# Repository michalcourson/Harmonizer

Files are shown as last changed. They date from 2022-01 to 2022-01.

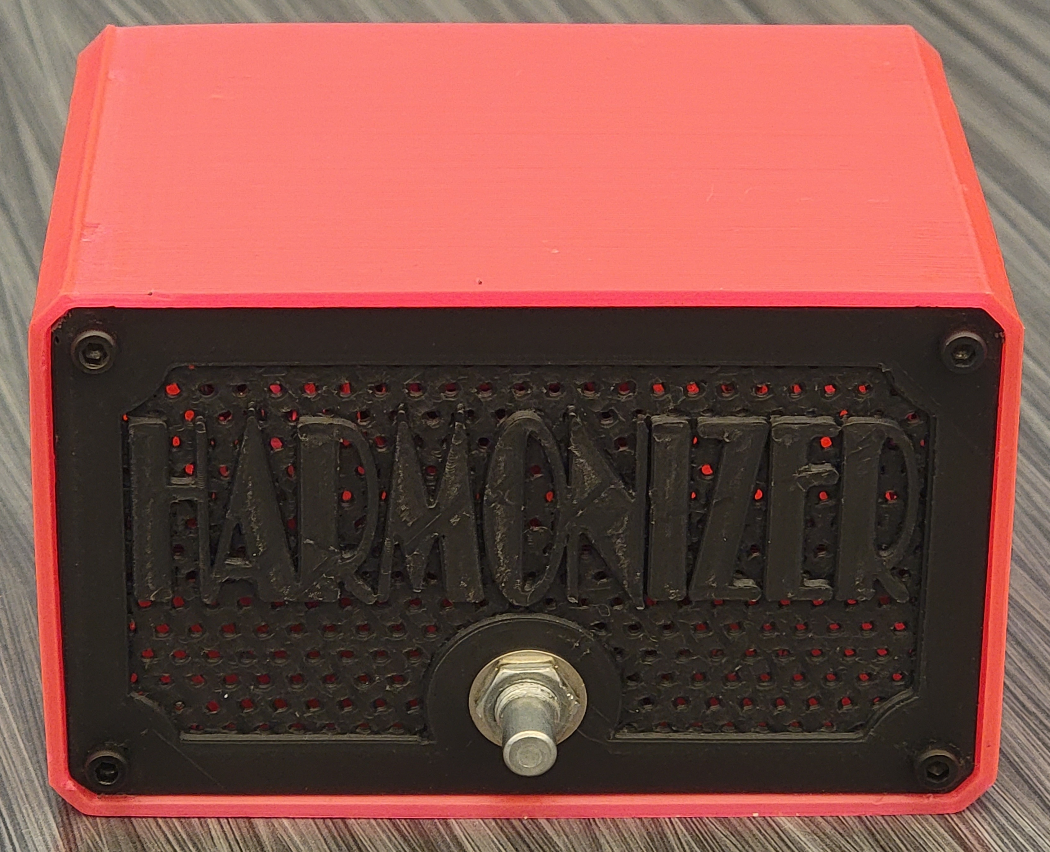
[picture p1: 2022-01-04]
design/assembly_images/Harmonizer_face.png

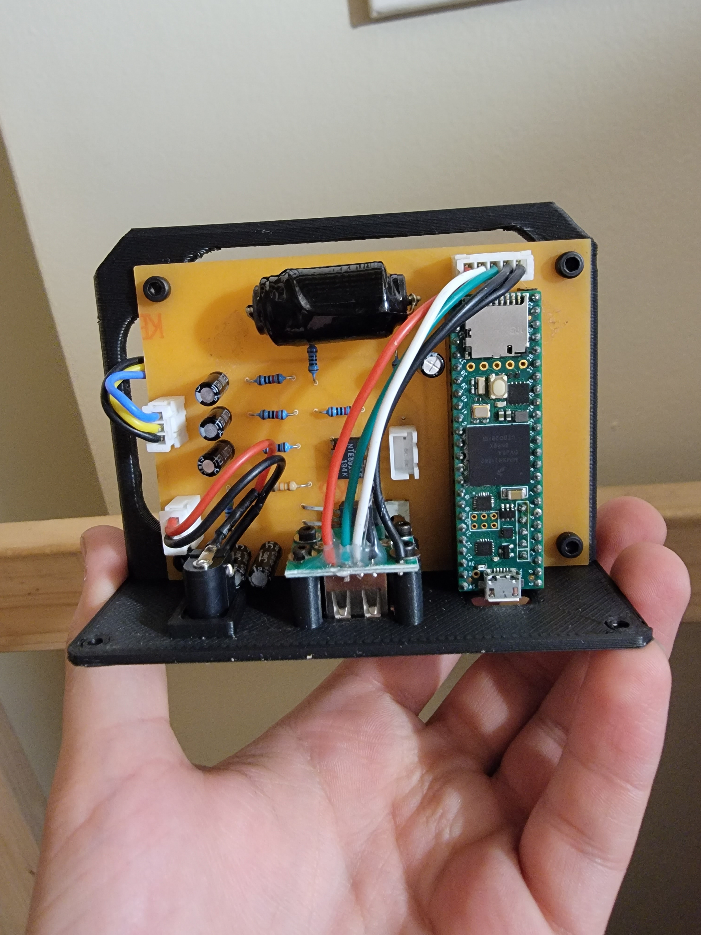
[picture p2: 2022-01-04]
design/assembly_images/Harmonizer_internal2.png

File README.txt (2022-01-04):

Team members:
	Audrey Cooke
	audeo@umich.edu
 
	Michal Courson 
	mcourson@umich.edu
 
	Daniel Kohler
	danikohl@umich.edu
 
	Allanah Matthews
	allanahm@umich.edu
 
Zipfile Contents:
COPYRIGHT.TXT
	--Document which highlights the necessary copyright provisions for the Harmonizer project

2021-Team-Harmonizer-final.pdf
	--Final report for the Harmonizer project.  

2021-Team-Harmonizer-slides.pdf
	--Final presentation slide-deck to be presented in class. 
 
2021-Team-Harmonizer-poster.pdf
	--Final project poster to be presented at the Fall 2021 CoE Design Expo

vidoes 
	--Folder which includes real time demonstration videos of the Harmonizer for our final presentation slides

src 
	--Folder which contains the source code for our project
		--Includes code written for the offline python and offline C++ prototypes of our algorithms.  
		Each offline folder includes its own USAGE.TXT to outline how to use the code.

		--The OVERVIEW.TXT file provides an overview of each embedded code file needed for the Teensy.
		It also gives a basic overview of the software operation of the system. 

		--The USAGE.TXT file contains user-interface information which details the designated inputs 
		and outputs for the Harmonizer on the Teensy itself. 

		--The INSTALL.TXT file contains instructions for software installation on the Teensy.  It also 
		details the designated folder locations for specific files in order for the Harmonizer to successfully run in real time. 

		--The to_audio_library_folder houses the files which need to be stored in the Audio folder for the Teensy.

		--The to_core_teensy4_folder houses the files which need to be stored in the CoreTeensy4 folder for the Teensy. 

		--The harmonizer folder includes the .ino file which needs to be compiled on the Teensy in order for the system to operate in real time. 
data 
	--The audio subfolder includes results of pitch shifting a tritonal signal (at a note frequency of C3) using the TD-PSOLA algorithm, 
	the Phase-Vocoding algorithm, and both of these algorithms together with crossfading implemented at the switching threshold.  
	The results from each of these tests can be compared to Target_Output.wav

	--The figures subfolder includes images and plots which are used in the final presentation and final report. 

design 
	--This folder houses subfolders which are designated for files associated with the PCB design, the package design and images of the assembly process.
  
	--The pdf for bill of materials is also included in this folder (not included in its own subfolder).

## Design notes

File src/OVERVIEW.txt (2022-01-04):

OVERVIEW
Files:
harmonizer/harmonizer.ino: driver sketch to be loaded onto a Teensy 4.1, 
instantiates Audio processing objects that pitch shift the input signal. Four concurrent shifts are mixed together and sent to the output.

to_audio_library_folder/analyze_notefreq.cpp/analyse_notefreq.h: modification of Audio Library pitch estimator to work with block size of 1024

to_audio_library_folder/Audio.h: modification of Audio Library file to include effect_pitch_shift.h

to_core_teensy4_folder/AudioStream.h: modification of Audio Library Stream objects to use block size of 1024 instead of 128

to_audio_library_folder/effect_pitch_shift.cpp/effect_pitch_shift.h: Definition and implementation of new processing object to perform pitch shifting

BASIC OPERATION
The Audio Library has an infrastructure that calls the virtualized update() function on any object
whenever a new input block is passed to it. This is done with a soft interrupt and requires no 
direct programmer interaction. More information on the Audio infrastructure can be found here: https://www.pjrc.com/teensy/td_libs_Audio.html. 

Control flow for this sketch is then mostly handled by the infrastructure, processing the audio
and then sending it to the next object to handle. The rest of the sketch handles MIDI events and
changes parameters within the pitch shifting objects accordingly.

Due to the run time of our algorithms, we decided to only have 4 shifts running concurrently. To
keep track of the active voices, we use a saturating circular buffer with a capacity limit of 4
and a FIFO eviction policy. As a MIDI signal is received, its value (0 to 127) is pushed to the
buffer. If there were already 4 keys pressed, the buffer evicts the oldest pressed note and adds
the newest pressed note. This ensures that there are always at most 4 active notes, even when more
than 4 MIDI keys are pressed. Finally, notes are removed from the buffer when they are released on
the controller. The buffer is called “NoteQueue” and the class definition is found in harmonizer/harmonizer.ino.

The pitch shift algorithms need to know the pitch of the input signal. For this, we use a version
of the Teensy’s AudioAnalyzeNoteFrequency object which has been modified to work with an audio
sample size of 1024 rather than the Audio.h library’s default of 128. In addition, the pitch shift
algorithms need to know the target pitch. For this, a simple function is called to convert the MIDI
note value (0 to 127) into a target frequency. Together, the analysis pitch and target pitch are
used to determine the shift amount that is then performed by the algorithms.

In testing, we noted that Phase Vocoding had better performance on target frequencies lower than an
octave below the analysis frequency than did TD-PSOLA. As such, we implemented a crossfade between
the two algorithms for these low frequencies. This allows for much better audio quality when shifting to lower frequencies.

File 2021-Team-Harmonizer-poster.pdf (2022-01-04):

# Harmonizer

# EECS 452: Digital Signal Processing Design Lab – Winter 2021 Audrey Cooke, Michal Courson, Daniel Kohler, Allanah Matthews

# Introduction

# Innovations

# System Architecture

Algorithms and Techniques | Results and Findings

# Acknowledgements

The Harmonizer is a device that allows a single musical performer to sound as if they were a full ensemble. This device is capable of taking in any monophonic signal as an input, and then pitch shifting that signal to user-controlled notes up to 4 times concurrently, all in real-time. This allows a performer to create harmonies on the fly. The ability to harmonize with yourself in real-time is a novel experience for most musicians and thus can provide both inspiration and new possibilities for live performance.

The Harmonizer takes input via a USB MIDI controller plugged into its USB host port, or by way of a computer running MIDI-capable software such as MIDI-OX or Ableton Live. In order to shift a note to a given pitch, the Harmonizer makes use of two algorithms: Time Domain Pitch Synchronous Overlap and Add (TD-PSOLA) and Phase Vocoding (PV).

The Harmonizer uses two algorithms to perform the real-time pitch shifting: Time Domain Pitch Synchronous Overlap and Add (TD-PSOLA) and Phase-Vocoding (PV). TD-PSOLA works in the time domain by adjusting the spacing between the peaks corresponding to the fundamental frequency, while PV works in the frequency domain by synthesizing phase shifted versions of the input to time stretch and then resample the signal. In our device, the signal is pitch-shifted using TD-PSOLA unless it is being shifted down by about an octave or greater, at which point, it is processed using PV.

Figure 3: Visualizations of Phase-Vocoding (left) and TD-PSOLA (right).

Figure 1: High-level block diagram of the Harmonizer. Inputs are on the left and outputs are on the right.

The team would like to thank Marion Anderson and Professor Shai Revzen for their support and guidance throughout this project. This project was inspired by the instruments used by Bon Iver and Jacob Collier, and made possible through funding from the College of Engineering at the University of Michigan, Ann Arbor.

At the core of the Harmonizer is a Teensy 4.1 equipped with an audio shield, capable of processing audio with a sample rate of 44.1kHz. The Teensy rests on a specialized PCB that provides power to the controller. In addition, the PCB implements a balanced microphone preamp that makes it possible to use professional-grade microphones as input to the device. The preamp also makes use of a second-order low-pass filter to eliminate frequency components above the Nyquist frequency (22.05kHz). This prevents high-frequency noise from interfering with the DSP that takes place on the Teensy.

Figure 2: Circuit schematic of preamp and power circuit. Unbalanced input from microphone is converted into a balanced signal for the audio shield.

To test the effectiveness of the shifting algorithms, a tritonal sinusoidal signal comprised of equal-magnitude harmonic components at f0=261.63 Hz, f1=2*f0
, and
f2=3*f0

was fed into the Harmonizer for a total of 49 seconds. In intervals of one second, the harmonizer was sent shift targets in the form of MIDI notes representing semitones from 65.41 Hz (C1) to 1046.50Hz (C5), a total of 49 individual notes spanning four octaves. The results were compared against the frequency spectrum of tritonal sinusoids generated with f0
in the same range.

The Harmonizer is implemented in an all-in-one embedded platform to increase accessibility and portability while minimizing the need for time-consuming configuration and expensive software. With onboard class-compliant MIDI methods, the Harmonizer is versatile, able to be controlled with a computer for automation or a keyboard for real-time human interaction.

The Harmonizer has a unique method for blending two pitch shifting algorithms to get the maximum output quality in different frequency ranges. Algorithm transitions depend on the ratio of target frequency to input frequency, known as the shift ratio. Below a shift ratio of 0.5, Phase Vocoding is used. Above a shift ratio of 0.7, TD-PSOLA is used. A crossfade between the algorithms takes place for shift ratios between 0.5 and 0.7.

Challenges inherent to the project included ensuring a processing speed high enough to be able to compute and playback the altered signal with the real-time input. A sharp tone change in the input causes a slight delay with the harmonized outputs.

Testing revealed that Phase Vocoding is ideal for lower frequencies due to attenuation of the low frequencies for shift ratios below 0.5 when using TD-PSOLA. On the contrary, TD-PSOLA is ideal for higher frequency components due to less aliasing as compared to Phase Vocoding.

The performance of the shifting algorithms was tested by measuring the elapsed time while processing a block of 1024 samples on the Teensy 4.1. TD-PSOLA takes an average of 50 microseconds while Phase-Vocoding takes an average of 5317 microseconds. Phase-Vocoding is just fast enough to run 4 concurrent shifts.

Figure 5: Runtime measurements of TD-PSOLA (left) and Phase-Vocoding (right).

Figure 5: Tuner output after shifting using TD-PSOLA (top) and PV (bottom).

Figure 3: Spectrograms of synthesized target output frequency spectrum (top left), TD-PSOLA shifted signal (bottom left), Phase Vocoding shifted signal (bottom right), and crossfading method (top right).

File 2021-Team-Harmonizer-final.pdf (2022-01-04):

# Harmonizer

Audrey Cooke, Michal Courson, Daniel Kohler, Allanah Matthews

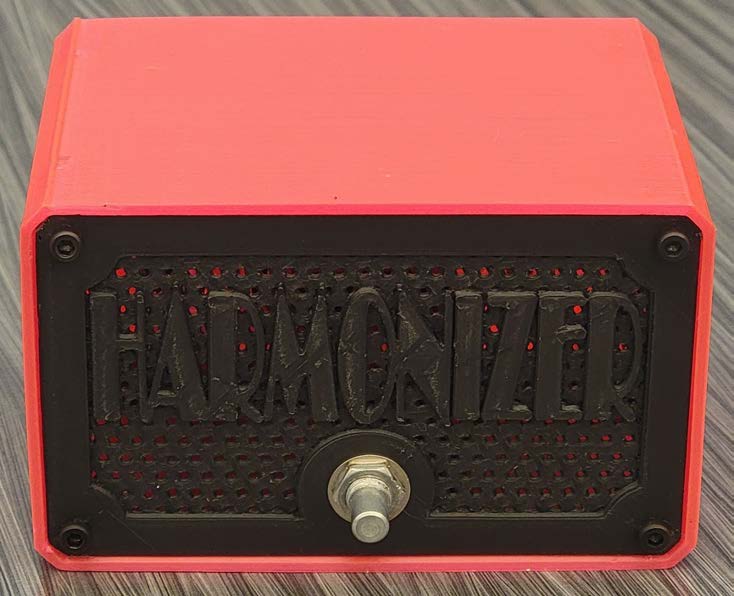
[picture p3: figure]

Table of Contents
Introduction | 3
High Level Overview | 3
Hardware | 3
TD-PSOLA | 4
Phase-Vocoding | 4
Granular Synthesis | 5
Technical Issues | 5
TD-PSOLA | 5
Phase-Vocoding | 6
Granular Synthesis | 6
MIDI | 6
Testing | 7
Results | 7
Intonation | 7
Frequency Performance | 8
Algorithm Speed | 8
Hardware Verification | 9
Discussion | 9
Future Work | 10
References | 11
Appendix A: Circuit Schematics | 12

Introduction
The underlying purpose of any piece of musical technology is to both inspire artists to create new and interesting sounds, and to help them communicate with their audience. Our Harmonizer is an attempt to fulfill that purpose. This device is capable of pitch shifting any monophonic signal to a set of user-controlled musical notes. This allows the performer to create harmonies on the fly without the need for additional performers. The ability to harmonize with yourself in real time is a novel experience for most musicians, and thus can provide both inspiration and new possibilities for live performance.
There are a few devices similar to ours out in the world, but they are mostly custom built and tailored to the needs of specific artists. A few notable examples are Justin Vernon’s instrument, “the Messina,” which was created by Chris Messina, as well as Jacob Collier’s harmonizer, built by MIT alumni Ben Bloomberg. Both devices are Frankenstein amalgamations of custom DSP processing code and commercially available hardware and software.[1][2] Our implementation, in contrast, uses only a Teensy 4.1 microprocessor to perform the required shifting operations. Our hope is that the simplicity of the Harmonizer makes this category of device more accessible to artists without a technical background.

High Level Overview

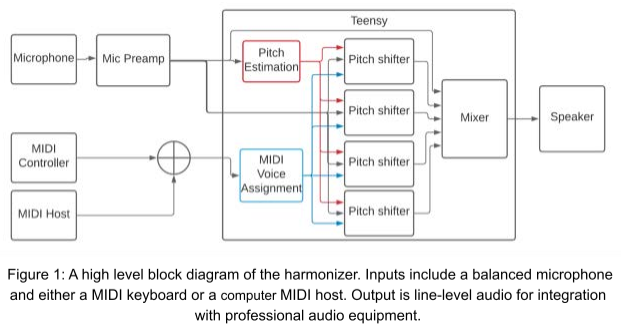
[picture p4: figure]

Hardware
The Harmonizer is implemented in embedded C code on a PJRC Teensy 4.1 microcontroller. The Teensy is equipped with PJRC’s Teensy Audio Shield, which implements an audio codec with a sample frequency of 44.1kHz. For increased compatibility with professional audio equipment, the device takes input directly from a balanced [6] microphone via an XLR cable and outputs to a ¼” patch cable.
To convert the balanced signal into unbalanced audio for the Audio Shield, the Harmonizer implements a simple microphone preamp. This preamp consists of an analog differential voltage converter, a second-order low pass filter with a cutoff frequency of 15kHz, and a microphone gain stage controlled by a rotary potentiometer. The output of the conversion circuit is fed into the Line In audio port on the Audio Shield. Finally, the Audio Shield outputs the processed audio signal at line-level for performance or recording.
Powering the system is a ground shift circuit which provides ±5v rails to the op amps in the conversion circuit, and provides power to the teensyand USB devices. The harmonizer connects to either a computer via the Teensy’s onboard micro USB port, or to an external MIDI keyboard via a USB-A host port. The schematics of these circuits may be found in Appendix A.

TD-PSOLA
Time Domain Pitch Synchronous Overlap and Add (TD-PSOLA) is the primary algorithm that performs pitch shifting in the Harmonizer. The algorithm is explained in depth in [3]. TD-PSOLA performs pitch shifting by changing the spacing in between the peaks of each cycle of the input fundamental frequency. This is done generating
"pitch markings" at each of these peaks, computing
new "pitch markings" that are spaced according to

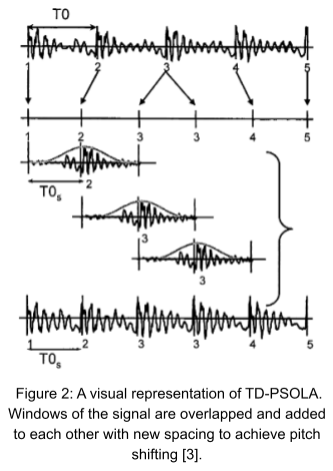
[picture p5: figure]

the target fundamental frequency, and then overlapping windows of the original signal centered on the new pitch markings. Figure 2 is a visual representation of this process.
TD-PSOLA was chosen for two reasons. Firstly, the algorithm preserves the characteristic high-frequency components of the input, which helps the shifted audio to sound more natural. Furthermore, TD-PSOLA is very fast. Since this algorithm processes the signal exclusively in the time domain, it can be made extremely efficient.
Phase-Vocoding
Phase-Vocoding (PV) is the secondary algorithm we are using to pitch shift the input signal. The algorithm is implemented through an analysis-synthesis process. In the analysis stage, the FFT is taken on two consecutive windows of the input signal, separated by a constant hop size known as the “analysis hop.” Phase and magnitude calculations are then performed on each respective bin of both FFTs in order to synthesize the new frequency domain version of the original signal. The inverse FFT is then taken on the synthesized result to get the signal into the time domain.
Overlap and add is performed on consecutive synthesized results, and the overlap amount is determined by the “synthesis hop”. The analysis hop size to synthesis hop size ratio must be equivalent to the pitch shift ratio, or else the time stretched output will not be correct. The final step is to resample the time stretched version such that the pitch shift has been made. Figure 3 demonstrates this process [3].

Granular Synthesis
Granular Synthesis is an audio construction method that splits a signal into smaller pieces between 1-100ms known as grains [4]. Grains can be altered in frequency and intensity, may be arbitrarily re-ordered, and even layered on top of one another [4]. Altering the pitch of a grain requires stretching and resampling, which alters the duration of that grain. To change pitch independently of time, grains can be repeated or removed, known as looping and extracting respectively. A similar method can be used to change the time duration without affecting the pitch. Grains are generally windowed to attenuate the beginning and end of the grain to facilitate a smooth transition between grains. Discontinuities on grain boundaries create a clicking noise that can be unpleasant [5]. In addition, leaving too much space between the grains causes noticeable gaps as if the signal was going through a fan. The length of grains and use of windowing can be manipulated to change the characteristics of the output of Granular Synthesis

Technical Issues
TD-PSOLA
One of the trickiest things to get right when implementing TD-PSOLA for real-time is getting seamless transitions between audio blocks. These transitions from one block to another can happen at any spacing from the nearest pitch marking. This means that special care must be taken to track where the rollover from each block starts and ends. Getting this wrong causes instantaneous jumps in the audio, causing "popping" sounds in the output. A solution to this problem is to use a buffer to hold on to the rollover from the last processed block, making sure the first pitch marking for the output is spaced relative to the last pitch marking from the last block. This ensures consistent
spacing over multiple blocks.
Another issue faced with TD-PSOLA relates to the

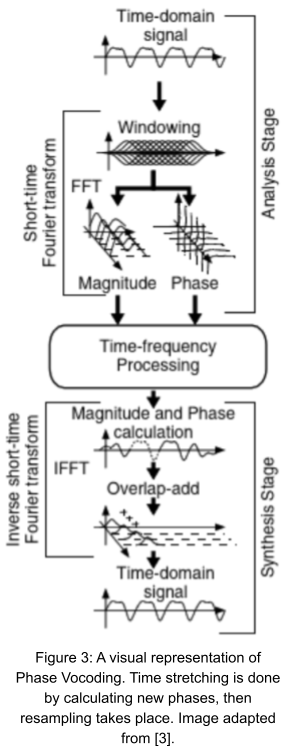
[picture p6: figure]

lowest frequency that the algorithm could output. When calculating the size of the window applied to the input signal, there are checks to make sure that no array out of bounds errors occur. The window size is shrunk in the case where these errors could happen. This means that the combination of a large enough window size (a fundamental frequency with a large period) and an input buffer that is too small, the window size on the last iteration for a block could be very small, leading to a section at the beginning of the next block that is silent. The output therefore had a choppy quality to it, where there were occasional gaps of silence that lasted for a few milliseconds when the target pitch was a low frequency (around 120 Hz and below). The issue was solved by delaying the output by a full block of 1024 samples so the algorithm had access to a whole block "in the future" and didn't need to adjust the window size as often.

Phase-Vocoding
The hardest part of Phase-Vocoding to get right is the synthesis phase calculations. Early iterations of the C++ offline implementation produced low quality output due to incorrect phase calculation for the negative half of the FFT array. Shifted signals suffered from unpleasant clicks and pops as the phases between consecutive synthesis windows were inconsistent. To fix this issue, phase calculations were only made for positive frequencies, and negative frequencies were set to the complex conjugate of the corresponding positive frequency. This resulted in smooth output.
Upon translation of the offline version into the realtime version, the primary issue encountered was that the algorithm could not process the input fast enough before the next input block came in. Initially, the Audio Library infrastructure was using a block size of 128 samples (about 2.9ms at 44.1 kH). Early online implementations of Phase-Vocoding took roughly 17ms to process. The delays induced by the slow speed of the algorithm resulted in unpleasant audio output. To fix this issue, the Teensy Audio Library infrastructure was modified to use a block size of 1024 instead of the default 128, changing the amount of time available to process a block to roughly 23.2 ms. However, this version was still too slow to run multiple concurrent pitch shifts. To fix this, the open source FFT algorithm used was swapped to the ARM-CMSIS RFFT implementation which is much more heavily optimized for the ARM Cortex processor on the Teensy. In doing so, processing time dropped to an average of roughly 5 ms per block, allowing for up to four concurrent shifts.

Granular Synthesis
The first issue faced while prototyping Granular Synthesis in Python was completely silent output. The WAV files produced consisted of data arrays filled with zeros. However, the output was the same length as the input. The issue resulted from a data type mismatch as floating point numbers from 0-1 were directly cast into 16 bit integers without any scaling.
Once the number format mismatch was fixed, a larger issue was revealed regarding the quality of output. Shifted audio sounded as if it were played through a fan, indicating discontinuities between the grains in the output. There was also a perceptible, consistent low frequency noise that seemed to be correlated with the grain size
With these two artifacts arising, Granular Synthesis failed our quantitative testing metrics as the pitch detection algorithms failed to recognize a fundamental frequency from the output. After much investigation, assistance from faculty, and significant debugging time, the cause of these artifacts could not be determined, so development of Granular Synthesis was not further implemented. A possible solution could be to use the Granular Synthesis method implemented in the Teensy Audio Library. However, the algorithm was developed to sound "glitchy" and did not fit the specifications of this project.

MIDI
The Harmonizer uses a class-compliant USB MIDI interface implemented in the USBHost_T36 Library [7]. The use of this interface allows the user to send MIDI signals from either a computer running a Digital Audio Workstation such as Ableton Live, or from a USB MIDI keyboard such as the

M-Audio Oxygen 49 digital piano. Due to timing constraints induced by Phase-Vocoding, it was decided that the Harmonizer would be programmed to shift no greater than four voices at a time. Since multiple keys can be played simultaneously on a keyboard, a method was needed to limit the number of active voices at a time. This goal was
achieved through the use of a saturating circular
buffer. The MIDI buffer adds each newly received
MIDI note to a circular array, and evicts notes either upon saturation or note release.

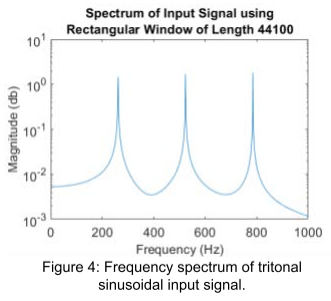
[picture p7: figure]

Testing
In order to quantitatively test the effectiveness of the Harmonizer’s pitch shift algorithms, a tritonal sinusoid was fed into the device and shifted ± 2 octaves in semitone steps. A tritonal sinusoid signal was chosen for input due to the existence of harmonics and high frequency components in human voice and many monophonic instruments. A tritonal signal allows for analysis of the effects of different shifting techniques on frequency components other than those at the base frequency of a tone.
The tritonal sinusoidal signal is comprised of equal-magnitude harmonic components at f 0 =261.63 Hz, f 1 =2*f 0 , and f 2 =3*f 0 . The signal was fed into the Harmonizer for a total of 49 seconds. In intervals of one second, the harmonizer was sent shift targets in the form of MIDI notes representing semitones from 65.41 Hz (C1) to 1046.50Hz (C5), a total of 49 individual notes spanning four octaves chromatically. Figure 4 shows the frequency spectrum of the input signal.

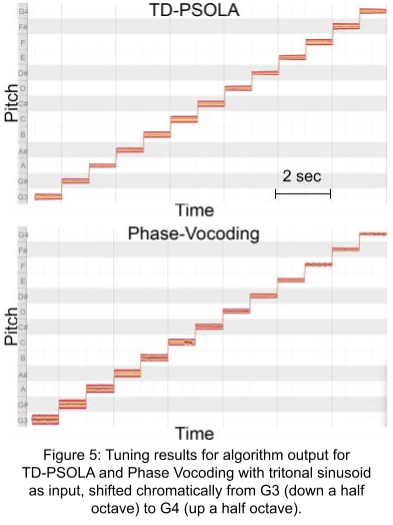
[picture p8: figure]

Results
Intonation
Truncated plots of the intonation of the tritonal sinusoid shifted using PV and TD-PSOLA are shown in Figure 5. In these plots, the y-axis is pitch (in semitones) and the x-axis is time. The thin orange line through the signal shows the pitch of the signal. When this line is in the middle of the row, it indicates that the signal is in tune.

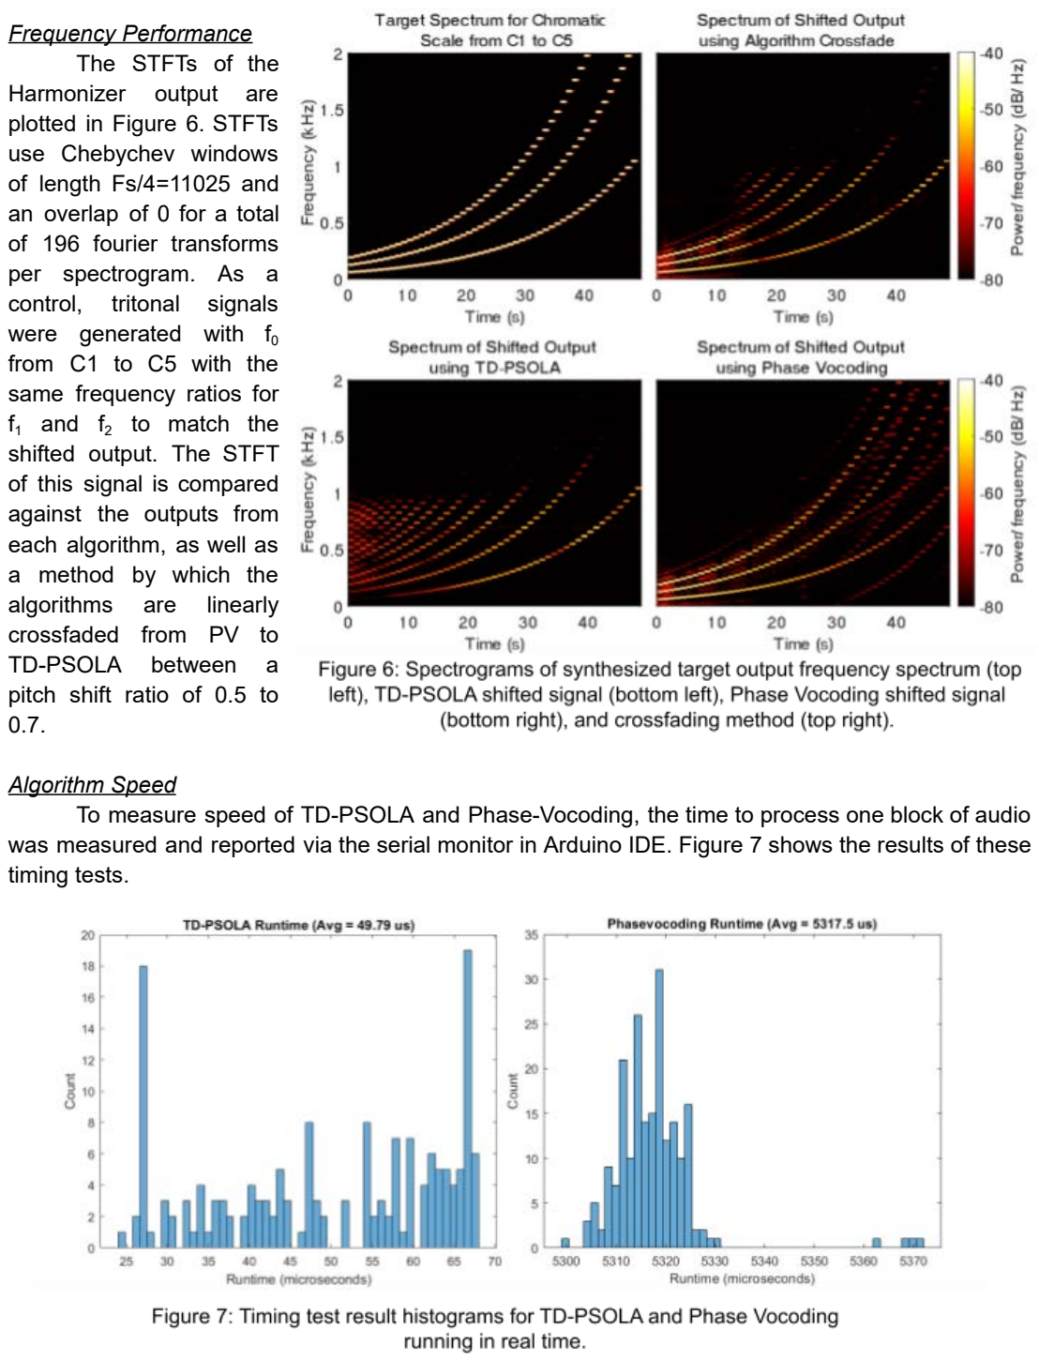
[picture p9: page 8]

Frequency Performance
The STFTs of the
Harmonizer output are
plotted in Figure 6. STFTs use Chebychev windows
of length Fs/4=11025 and
an overlap of 0 for a total of 196 fourier transforms
per spectrogram. As a
control, tritonal signals
were generated with f 0
from C1 to C5 with the
same frequency ratios for
f 1 and f 2 to match the
shifted output. The STFT
of this signal is compared against the outputs from
each algorithm, as well as a method by which the
algorithms are linearly
crossfaded from PV to
TD-PSOLA between a
pitch shift ratio of 0.5 to
0.7.

Algorithm Speed
To measure speed of TD-PSOLA and Phase-Vocoding, the time to process one block of audio was measured and reported via the serial monitor in Arduino IDE. Figure 7 shows the results of these timing tests.

Hardware Verification
Hardware verification was
performed using an oscilloscope to measure the steady state response of the preamp. The magnitude and phase of the response of the circuit are plotted in Figure 8.

Discussion
The tuning tests show that
both | Phase-Vocoding | and
TD-PSOLA are very good at
staying in tune and hitting the
target pitch. We know it's hitting

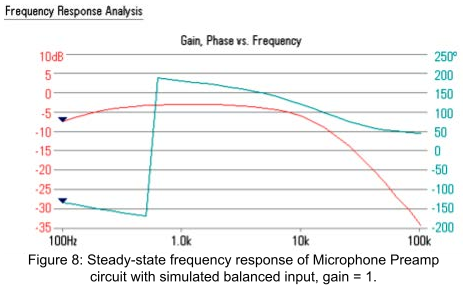
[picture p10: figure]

the target pitch in tune as the graphs show the output signal in the dead center of each row.
Through our testing, we found that the subjective quality of the output from TD-PSOLA is very good in most cases. Shifting the pitch down by an octave or more produces audio that could be described as "thin" as the pitch markers become far enough apart that there are sections in the output that are silent. Coincidentally, this range of shift factors is where Phase-Vocoding sounds its best. The alterations of the formants in this range are not as distracting as they are with higher shifts, where the "talking while inhaling helium" effect kicks in.
These subjective findings were also backed up by the expanded STFT tests. Looking at figure 4, it is clear that TD-PSOLA has much more frequency artifacts and attenuation of the base frequency at low shift ratios, but has very few artifacts for higher shifts. Phase-Vocoding, while not perfect, is much closer to the desired spectrum in the low shift range and produces a lot of frequency artifacts for higher shifts. The STFT results of the crossfade clearly show that our solution produces output that is closer to the target spectrum than either of the two algorithms alone.
During testing, it was found that TD-PSOLA takes an average of about 50 microseconds, which is much faster than needed. The theoretical limits of how many voices TD-PSOLA could process concurrently is upwards of 300. Phase-Vocoding, on the other hand, takes an average of 5.3 milliseconds, which is just fast enough to run 4 times concurrently. Since Phase-Vocoding runs much slower than TD-PSOLA, our implementation only lets Phase-Vocoding run if it is needed for any particular voice. This is realized in the algorithm crossfade method, by which Phase-Vocoding will run for a pitch shift ratio of 0.7 or less. In the common case, this would limit the amount of voices using Phase-Vocoding concurrently to one or two voices, leaving plenty of breathing room where processing time is concerned.
During testing of the final product, it was noted that plugging a USB device into the USB host port on the Harmonizer, as well as plugging the harmonizer into a computer via USB, resulted in audible digital noise interference. This is a common occurrence among audio equipment, and is known as ground loop interference. In some cases, this type of interference can be rectified using a ground loop isolator, but it is unclear whether in the context of the Harmonizer this approach would be sufficient. The cause of and solutions to this issue were not explored during the development of the Harmonizer, as the interference had only a minor effect on the quality of the device’s output.

Finally, there is a small but noticeable amount of latency of around 46ms when quickly switching the input note frequency. This latency is due to the fact that 1024 samples must be analyzed to calculate the base frequency, and an additional 1024 samples must be processed to generate the shifted output. This is especially noticeable when using an instrument such as a saxophone or flute, but less apparent when singing into the device.

Future Work
Future versions of the Harmonizer could increase the number of concurrent voices. This would entail modifications to shifting algorithms to optimize their complexity. The biggest bottleneck on performance is the runtime of Phase-Vocoding, as demonstrated in Figure 7. Due to the complexity of FFT algorithms driving the approach, it is unclear whether or not further optimization could substantially improve performance of the algorithm. The most promising route for increasing voices would be to modify TD-PSOLA to incorporate some of the aspects of Phase-Vocoding for pitch shifts more than one octave below the base frequency. This could potentially extend the range of TD-PSOLA lower than the current implementation, allowing for PV to be omitted.
More experimentation can be performed with Phase-Vocoding to categorize the effects of different windows on the output sound. The only window tested in PV was a Hanning window, which is used in the current real-time implementation of the algorithm. Qualitative output comparisons should be made using different windows in order determine which window results in a more pleasant sounding output.
To minimize latency, older versions of the Harmonizer used an analysis sample size of 128. This resulted in a latency of around 25 ms when switching the input note. However, the code base had to be modified to support Phase-Vocoding, switching the sample size of 1024 globally This resulted in the discussed latency of 46ms. In order to rectify this issue, future versions of the Harmonizer could implement a sample accumulation method for collecting 1024 samples for shift processing while maintaining the Audio Library’s default sample size of 128. This approach was explored with early versions of the TD-PSOLA implementation, but will require further research and optimization to be a viable solution.
The inclusion of Granular Synthesis in the Harmonizer was cut early on in the project. In future versions, it may be worthwhile to explore other methods of pitch shifting than the two implemented in the final version of the code. Issues present in Granular Synthesis could potentially be solved through the use of a linear adaptive filter or similar technique to improve the quality of its output. Other possible shifting methods include time stretch and resampling via nearest-neighbor interpolation and low pass filtering, or a similar method using linear interpolation or spline interpolation.
The Harmonizer could also be improved by adding more elements to the signal chain within code. Adding extra controllable effects would allow the user to be much more expressive while performing with the device. Some ideas that have been discussed are filters, reverb, delay, portamento, pitch delta control, as well as the ability to "freeze" a chord in a secondary looping buffer and then continue to play extra notes over that "frozen" chord.
The circuitry of the Harmonizer could be further improved to provide for more efficient, less noisy power delivery to the active components and the microcontroller. In addition, the audio preamp could be redesigned to minimize the effects of USB noise and ground loop interference on the output signal. Though these changes are not necessary, they definitely improve the experience when performing with the Harmonizer.

References
[1] Feist, E. (2017, November 17). How was Jacob Collier's harmonizer built? FloVoice. Retrieved from https://www.flovoice.com/articles/6001397-how-was-jacob-colliers-harmonizer-built.
[2] Petrarca, E. (2016, December 19). The sound engineer behind Bon Iver's "22, a million" clears up any confusion about its technical creation . W Magazine. Retrieved from https://www.wmagazine.com/story/the-engineer-behind-bon-ivers-22-a-million-clears-up-any-con fusion-about-its-high-tech-sound. (https://www.wmagazine.com/story/the-engineer-behind-bon-ivers-22-a-million-clears-up-any-confusion-about-its-high-tech-sound)
[3] Royer, T. (2019). Pitch-shifting algorithm design and applications in music . Retrieved from http://kth.diva-portal.org/smash/get/diva2:1381398/FULLTEXT01.pdf.
[4] Music Production Nerds (2021, January 7). Granular synthesis explained . Retrieved from https://musicproductionnerds.com/granular-synthesis-explained.
[5] Dobrian, C. Windows and Envelopes. Computer Music Programming. Retrieved from https://dobrian.github.io/cmp/topics/control-signals/4.Windows-and-Envelopes.html.
[6] B. Whitlock. (1995 June.) Balanced Lines in Audio Systems: Fact, Fiction, and Transformers. J. Audio Eng. Soc., vol. 43, no. 6, pp. 454-464,. Retrieved from http://davel.datatruck.com/Balanced%20Lines%20in%20Audio%20Systems%20-%20Bill%20Wh itlock%20-%20OCR.pdf. (http://davel.datatruck.com/Balanced%20Lines%20in%20Audio%20Systems%20-%20Bill%20Whitlock%20-%20OCR.pdf)
[7] Paul Stoffregen (2021). USBHost_t36. 2021. Github repository. Retrieved from https://github.com/PaulStoffregen/USBHost_t36.

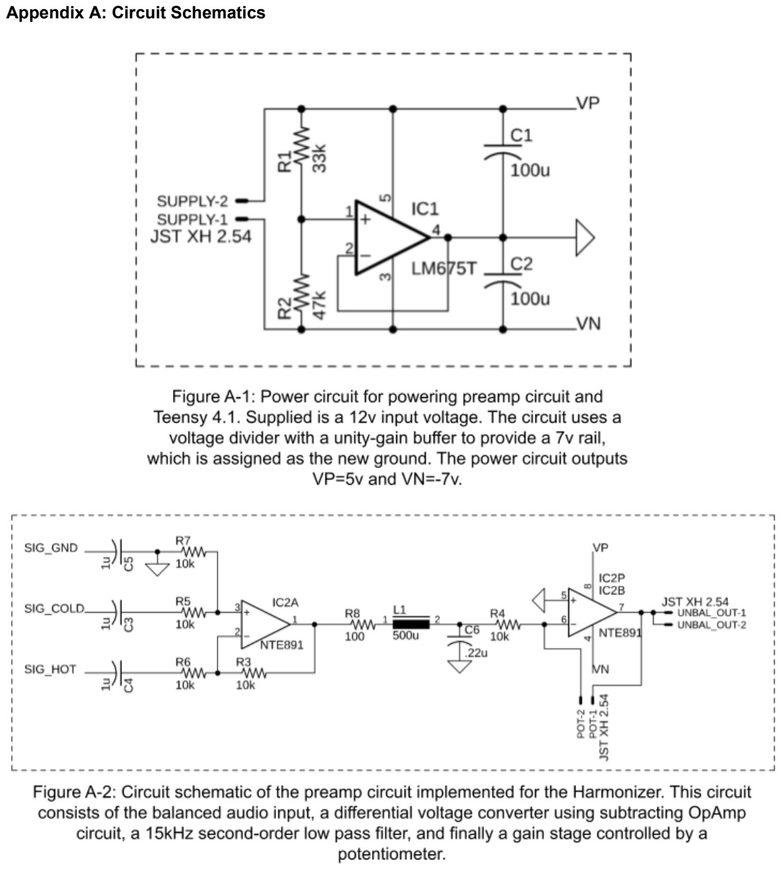
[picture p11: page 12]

Appendix A: Circuit Schematics

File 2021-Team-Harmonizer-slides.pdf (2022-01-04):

# Harmonizer

Audrey Cooke, Michal Courson, Daniel Kohler, Allanah Matthews

# Background

- The Harmonizer is a device to pitch shift monophonic input signals to user defined frequencies and mix these pitch shifted results to create a harmonious output.
- Using the Harmonizer, a single musician can create harmony without the dependence for accompanying musicians!

# Past Work

- Jacob Collier's Harmonizer -- PC with Ableton, dismantled TC Helicon, custom code on DSP hardware
- Bon Iver's Messina -- not a ton publicly known, Ableton does some preprocessing, sent to Eventide H8000 for pitch shifting with a proprietary algorithm
- Getting algorithms that sound "perfect" is difficult

# High-Level Description

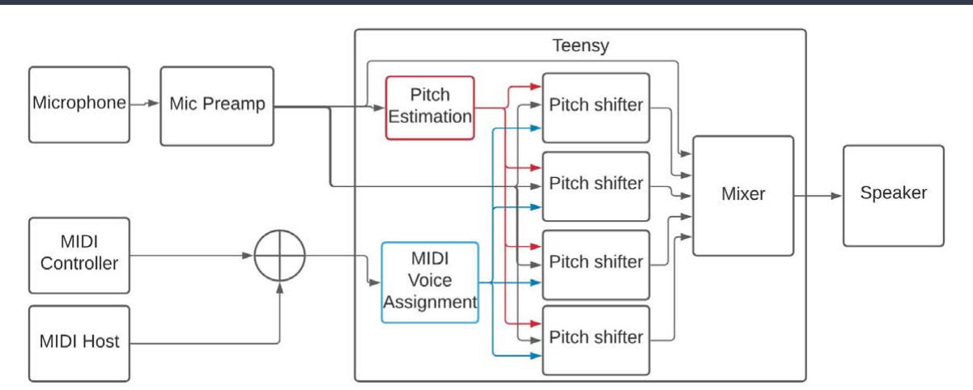
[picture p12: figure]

# Hardware Microphone

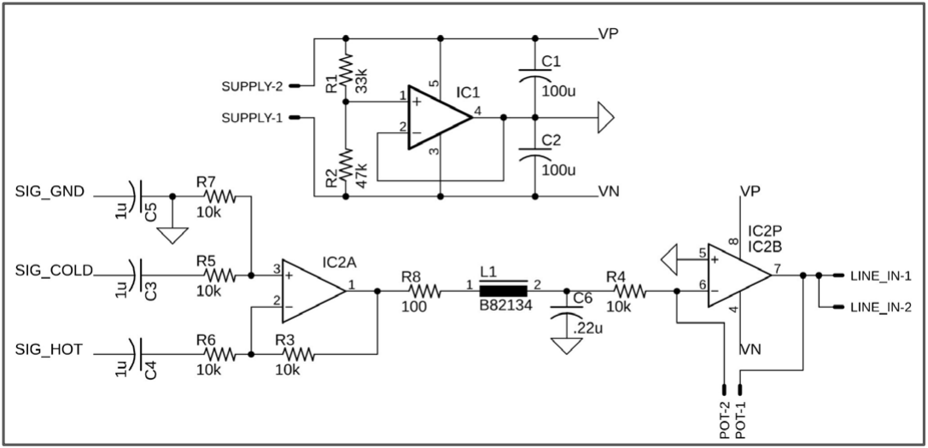
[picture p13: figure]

Teensy 4.1 and
Audio Shield

# TD-PSOLA

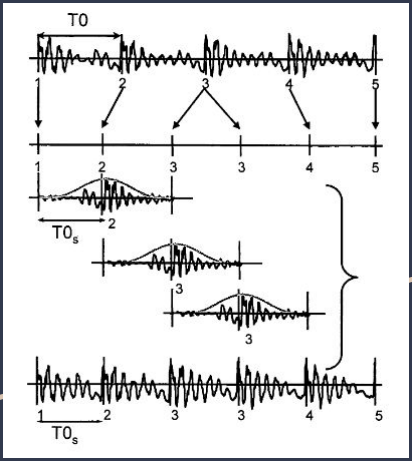
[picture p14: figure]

- Generate original signal pitch markings
- Calculate spacing of
new pitch markings
- Window two waveforms
of original signal
- Overlap and add
windowed waveforms
aligned with new pitch
markings

## Phase-Vocoding

- Perform RFFT on adjacent windows of input
- Separated by analysis
hopsize
- Perform phase shift on each RFFT window
- Perform IRFFT
- Perform overlap and add
- Separated by synthesis
hopsize
- Resample in order to
perform pitch shift

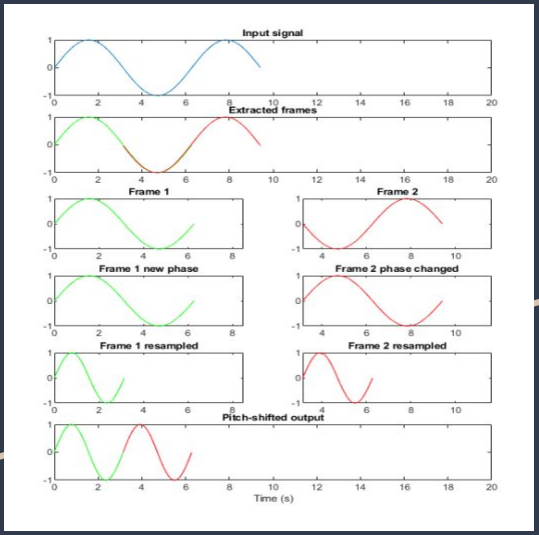
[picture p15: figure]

## Granular Synthesis

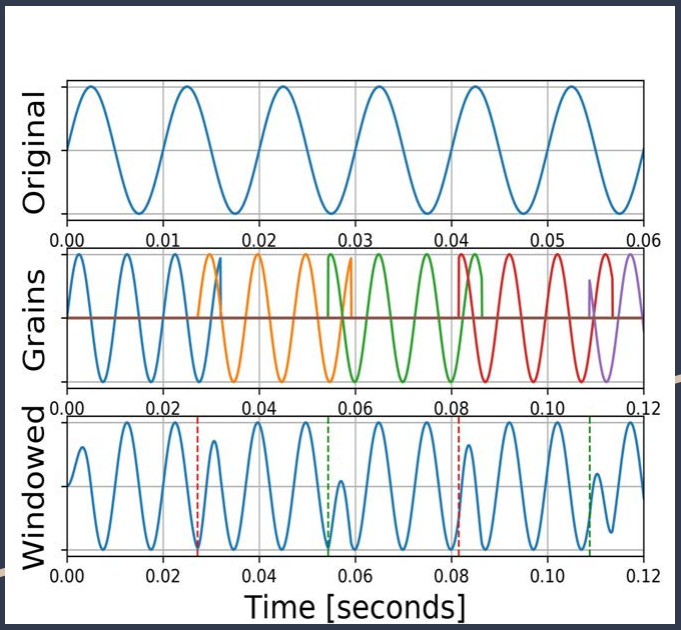
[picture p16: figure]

- Segment sections of
original signal
- Time stretch by copying and overlapping segments
- Use envelopes to smooth
discontinuities
- Resample to alter pitch

# Technical Issues

- Phase Vocoding
- Difficulty translating to C++ offline version due to differences in FFT implementations with Python
- Could not meet timing requirements on first iteration of real-time implementation
■ Had to switch FFT algorithms to meet timing requirement
- TD-PSOLA
- Pitch shifting to lower notes does not sound very good
- Granular Synthesis
- Output sound is not smooth
■ | Discontinuities in grains
■ | Frequency alias based on grain size

# Testing

- Monophonic - testing how well target pitch is hit
- Shift to every semitone +/- an octave
- Tuner should register each note as in tune
- Polyphonic - testing how "good" the algorithms sound
- Subjective timbre preferences
- Timing - testing how fast the algorithms run
- Arduino micros() function
- Must run fast enough to process before next block arrives

# TD-PSOLA Tuning Results

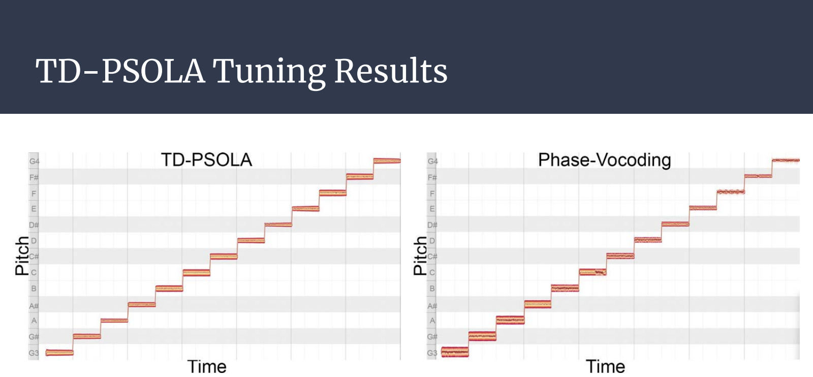
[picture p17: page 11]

## Algorithm Switching

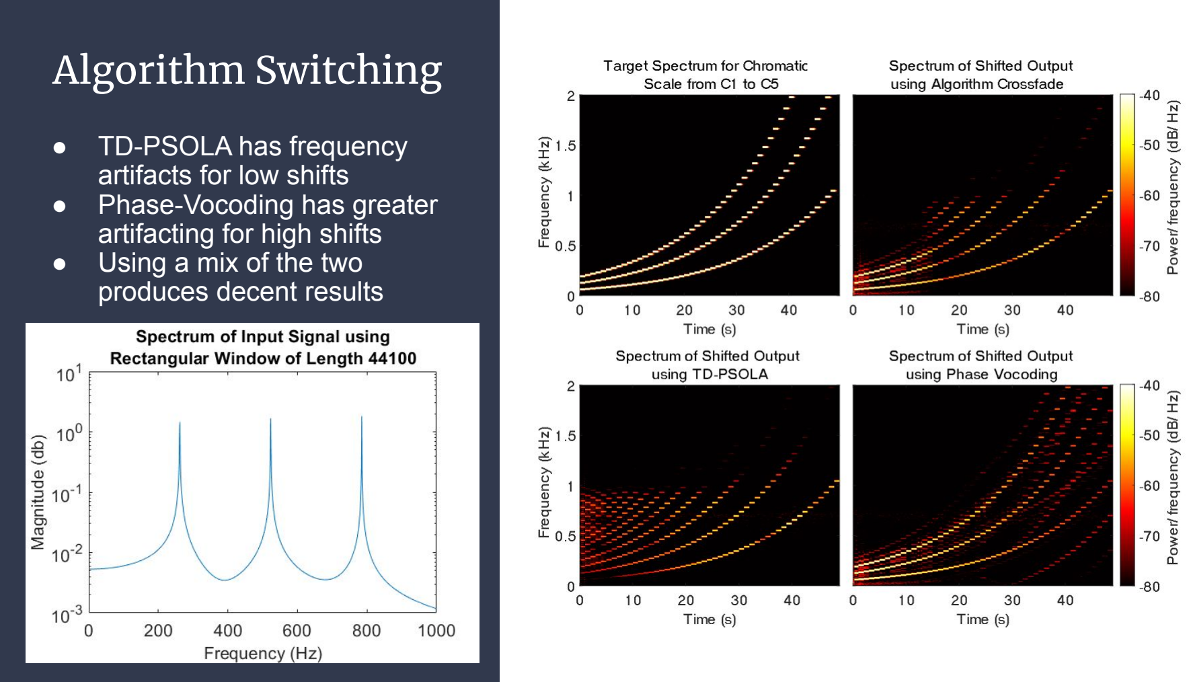
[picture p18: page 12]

- TD-PSOLA has frequency
artifacts for low shifts
- Phase-Vocoding has greater artifacting for high shifts
- Using a mix of the two
produces decent results

# Timing Results

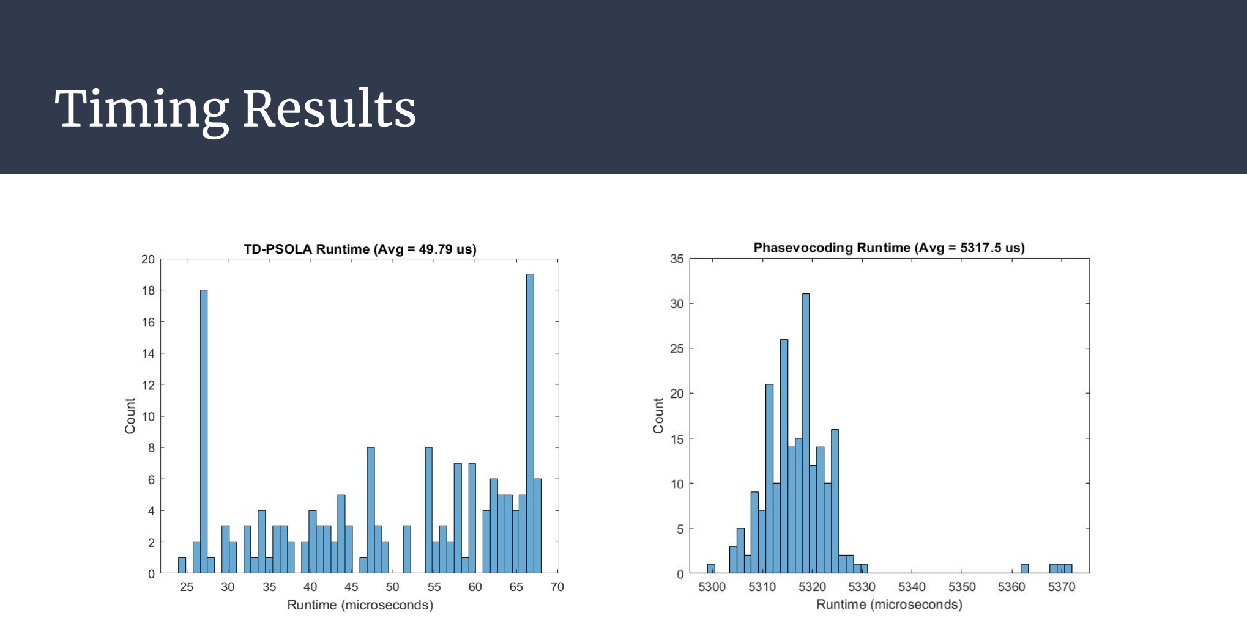
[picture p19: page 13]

# Results - Demo 1

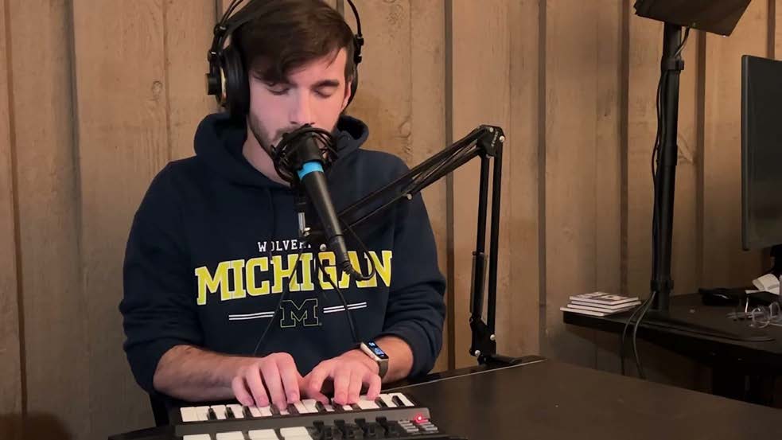
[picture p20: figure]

Hide_and_Seek.mp4 in videos folder

# Results - Demo 2

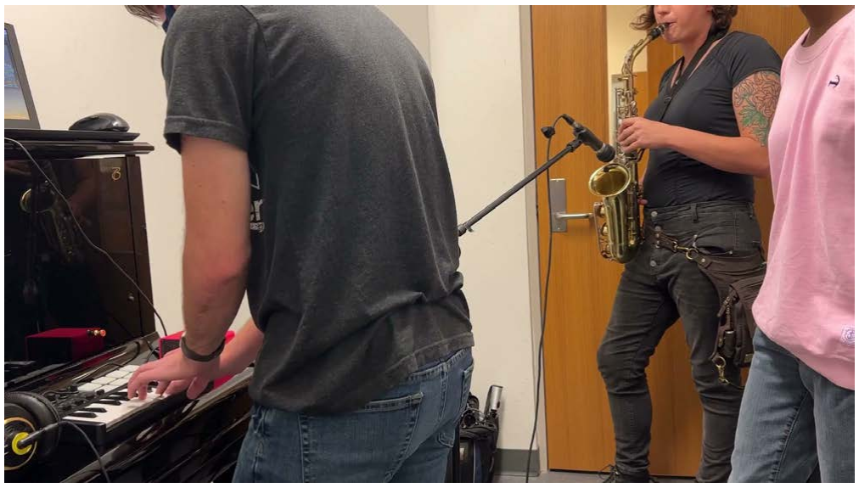
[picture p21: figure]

sax_improv.mp4 in videos folder

# Future Work

- Minimize latency
- Analysis algorithm optimization
- More concurrent voices
- Modify TD-PSOLA for low shifts
- Speed up Phase Vocoding
- Controllable effects
- Reverb
- Filters
- Delays
- Portamento
- Windowing
- Noise reduction
- Minimize ground loop interference
- Isolate audio hardware from power hardware

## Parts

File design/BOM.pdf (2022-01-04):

Total:
199.31
QTY SKU | DESCRIPTION | URL | PRICE | Subtotal
1 B089CQ2N69 | Fermerry 22AWG Stranded Wire, 6 colors, 5 ft | https::/www.amazon.com/dp/B089CQ2N69/ | 10.69 | 10.69
1 B09BDX69VX | Glarks 190Pcs 2.54mm Male and Female Pin Header kit https::/www.amazon.com/dp/B09BDX69VX/ | 19.99 | 19.99
1 B09BJN68C2 | LUOYIMAO USB Type A Female Socket Breakout Board https::/www.amazon.com/dp/B09BJN68C2/ | 9.99 | 9.99
1 B00M56M2UI | Neutrik NC3FP-1 Full Size 3-Pin F PNL MT XLR | https::/www.amazon.com/dp/B00M56M2UI/ | 4.95 | 4.95
1 B07D4BK8W4 | Antrader 5.5mm x 2.1mm Female DC Power Jack | https::/www.amazon.com/dp/B07D4BK8W4/ | 6.99 | 6.99
1 B08BNDL6DS | EEEEE 61 Values 1% 0.25w Resistor Book kit, 1Ω-10MΩ https::/www.amazon.com/dp/B08BNDL6DS/ | 13.99 | 13.99
1 B07Q86ZJ4Z | GTIWUNG 480Pcs JST XH 2.54mm Connector Kit | https::/www.amazon.com/dp/B07Q86ZJ4Z/ | 10.99 | 10.99
1 B01AZLA9XQ | DC12V 12v 2A Power Supply Adapter | https::/www.amazon.com/dp/B01AZLA9XQ/ | 6.99 | 6.99
1 B00J0ECR5I | HATCHBOX PLA 3D Printer Filament 1kg Roll | https::/www.amazon.com/dp/B00J0ECR5I/ | 22.99 | 22.99
1 B07R78KNMC | uxcell Single-Sided FR4 PCB Blanks | https::/www.amazon.com/dp/B07R78KNMC/ | 16.59 | 16.59
1 B07M914GKR | Hilitchi 240-Pcs 24 Values Black Electrolytic Capacitors https::/www.amazon.com/dp/B07M914GKR/ | 11.99 | 11.99
1 889-1820-ND | 1/4" Barrel Audio Connector | https://www.digikey.com/short/52dnd844 | 1.43 | 1.43
1 LM675T-ND | LM675T Op Amp | https://www.digikey.com/short/5q9d9mv3 | 7.11 | 7.11
1 2368-NTE891M-ND | NTE891M Op Amp | https://www.digikey.com/short/438qz7mt | 3.22 | 3.22
1 2197-31VJ501-F3-ND | 31VJ501-F3 Logarithmic Rotary Potentiometer | https://www.digikey.com/short/tw4j3bpb | 4.58 | 4.58
1 HM3340-ND | 1537N 500 uH inductor | https://www.digikey.com/short/pvftv3b7 | 6.22 | 6.22
1 TEENSY41 | Teensy 4.1 Microcontroller | https://www.pjrc.com/store/teensy41.html | 26.85 | 26.85
1 TEENSY4_AUDIO | Teensy 4.1 Audio Adaptor | https://www.pjrc.com/store/teensy3_audio.html | 13.75 | 13.75
QTY TYPE OF COMPONENT | VALUE OF COMPONENT | SYMBOLS
1 TEENSY 4.1 | n/a | TEENSY 4.1
1 TEENSY Audio Shield | n/a | TEENSY 4.1
3 Capacitor | 0.1μF | C3, C4, C5
1 Capacitor | 0.22μF | C6
2 Capacitor | 100μF | C1, C2
5 Resistor | 10kΩ | R3, R4, R5, R6, R7
1 Resistor | 100Ω | R8
1 Resistor | 33kΩ | R1
1 Resistor | 47kΩ | R2
1 JST XH 2.54 Male and Female 5 Pin | USB_HOST
3 JST XH 2.54 Male and Female 2 Pin | UNBAL_OUT, SUPPLY, POT
1 JST XH 2.54 Male and Female 3 Pin | INPUT
1 NTE891 OpAmp | n/a | IC2
1 LM675T OpAmp | n/a | IC1
1 XLR Jack | n/a | INPUT
1 DC Socket 5.5mm x 2.1mm | n/a | SUPPLY
1 1/4" Barrel Audio Connector n/a | Audio Shield Line Out
1 USB Host Port Breakout Board n/a | USB_HOST
2 24 Pin Male to Female Header n/a | TEENSY 4.1
1 Inductor | 500μH | L1
1 Potentiometer | 100kΩ Logarithmic | POT

# PCB BOM

# Shopping List

PLEASE NOTE: ALL URL'S WERE TESTED FUNCTIONAL AT THE TIME OF COMPILING THIS BOM. HOWEVER, DIGIKEY LINKS MAY NOT WORK. THIS IS A RESULT OF A FAULTY SHORTENED URL GENERATOR THAT (A. GENERATES A DIFFERENT SHORTENED URL EACH TIME THE SHARE ICON IS PRESSED, AS WELL AS (B. LEADS TO SOME LINKS BECOMING INVALID. IF THIS HAPPENS, SIMPLY SEARCH THE SKU ON DIGIKEY.COM.

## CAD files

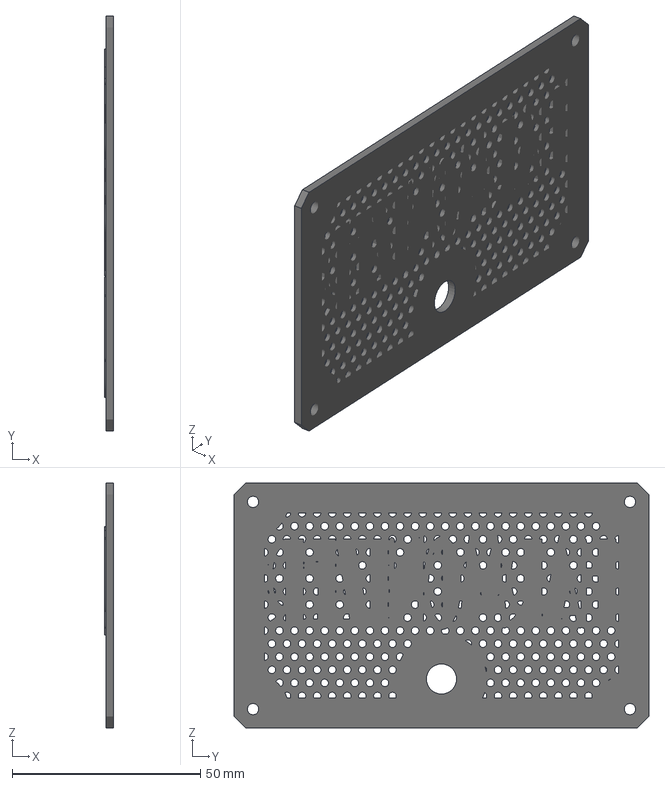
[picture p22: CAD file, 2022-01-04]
design/package_design/faceplate_mesh.3mf
2.50 x 110.0 x 65.0 mm

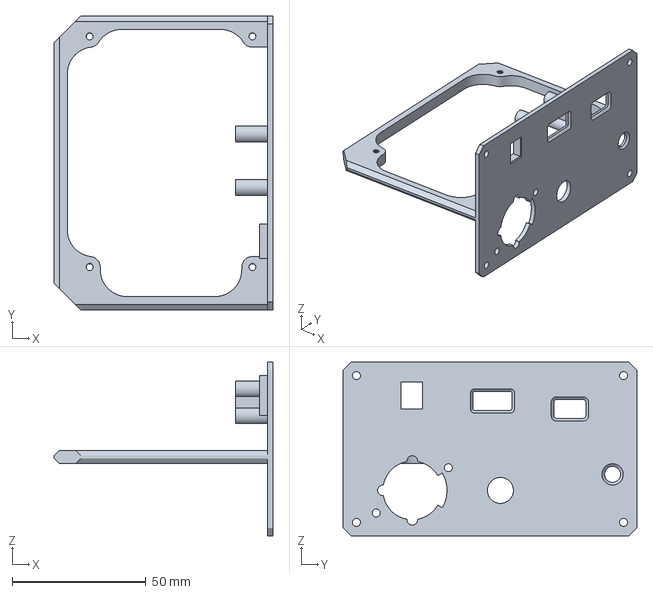
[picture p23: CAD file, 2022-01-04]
design/package_design/chassis_mesh.3mf
82.0 x 110.0 x 65.0 mm

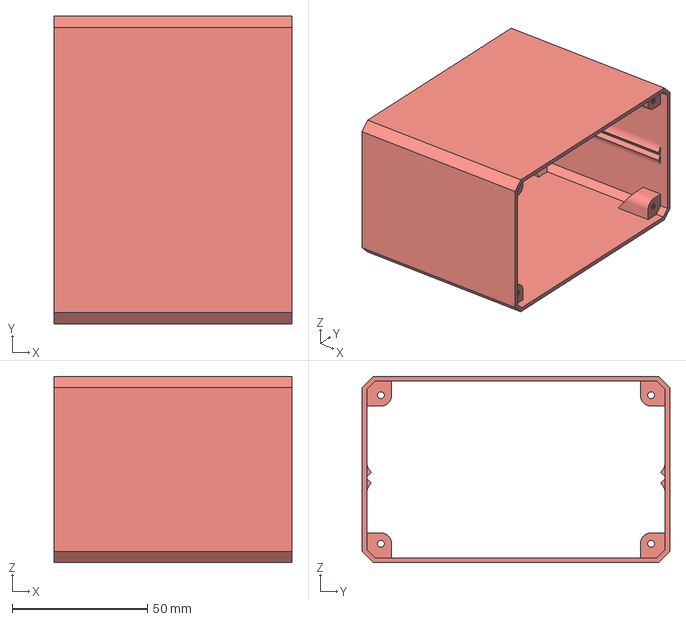
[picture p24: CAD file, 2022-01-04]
design/package_design/shell_mesh.3mf
88.0 x 114.0 x 69.0 mm

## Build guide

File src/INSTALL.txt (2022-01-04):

INSTALL
1. Install arduino IDE and teensyduino as instructed in the lab documents 
(Arudino 1.8.13 from https://www.arduino.cc/en/Main/OldSoftwareReleases#previous 
and Teensyduino from https://www.pjrc.com/teensy/td_download.html)

2. Copy 
	effect_pitch_shift.cpp
	effect_pitch_shift.h
	analyze_notefreq.cpp
	analyze_notefreq.h
	Audio.h
into the Audio library folder located at [Arduino]/hardware/teensy/avr/libraries/Audio

3. Copy
	AudioStream.h
into the Teensy Core folder located at [Arduino]/hardware/teensy/avr/cores/teensy4

4. Open the Arduino sketch .ino file, in Tools, set Optimize to Fastest, and USB Type to MIDI

5. Upload the sketch to the teensy

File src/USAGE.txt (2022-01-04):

A line level monophonic input should be sent into the line_in pins on the Teensy audio shield.
The hardware we designed converts an xlr mic output to this line level signal, but an 1/8"
audio source running directly into the audio shield will also work. The output will be sent
out of the audio shield and can be connected to headphones, speakers or a recording device. 

A USB MIDI controller can be directly plugged into the usb port that is connected to the header
pins on the teensy. MIDI control can also come from a separate USB host by plugging the Teensy
into the host with a micro-USB to USB-A cable. The Teensy should detect which type of connection
it is using should automatically be selectable as a MIDI output device on the host side. 

Once everything is connected, the user need only sing or play an instrument into the input while
using the MIDI control and the Harmonizer will output the pitch shifted harmonies.

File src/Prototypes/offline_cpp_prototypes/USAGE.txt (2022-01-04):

Usage for Offline C++
The structure of the C++ prototype is very similar to the final implementation that gets loaded
onto the hardware. The main difference is this version uses a separate driver program to feed
in audio as opposed to a microphone. To use this prototype, just compile test.cpp along with
effect_pitch_shift.cpp and run the executable.

The input wav file, output wav file, algorithm choice starting period in samples, and target 
period in samples are all defined by the user at runtime. If TD-PSOLA is the algorithm selected,
it is best to test with a wav file that only has one pitch, as it relies on having an accurate
starting period. Phase-Vocoding only relies on the ratio between the starting period and the 
target period so this is not an issue.

compilation command:
g++ --std==c+11 -O3 test.cpp effect_shift_pitch.cpp -o [executable name]

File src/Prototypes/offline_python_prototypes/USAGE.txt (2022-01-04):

Python prototype usage:
Each file is stand alone with corresponding imports of the modules below in the beginning of the
code. The code is commented to tell the user where they are able to modify lines in the program.
An example is the pitch in which the user can change the number. Each of these prototypes can
either take in a wav file or use a built in sine generator function. Outputs after shifting by
the amount specified in the .py file will be produced while running the code.

PYTHON MODULES TO INSTALL:
Numpy
Matplotlib
Scipy
Cmath
Sys
Wave
soundfile

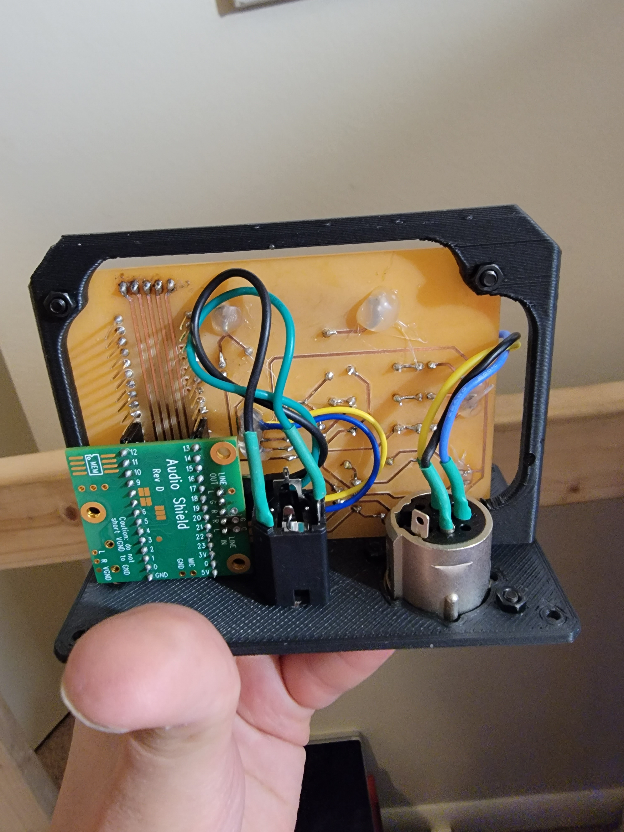
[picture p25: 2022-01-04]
design/assembly_images/Harmonizer_internal1.png

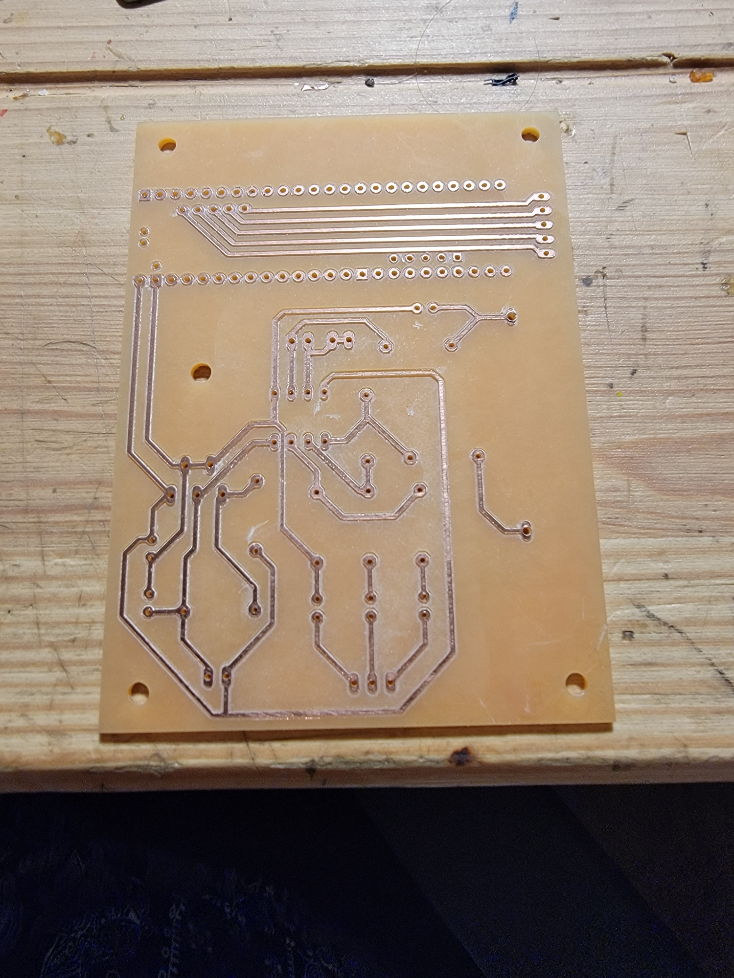
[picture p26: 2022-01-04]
design/assembly_images/Harmonizer_unpopulated_PCB.png

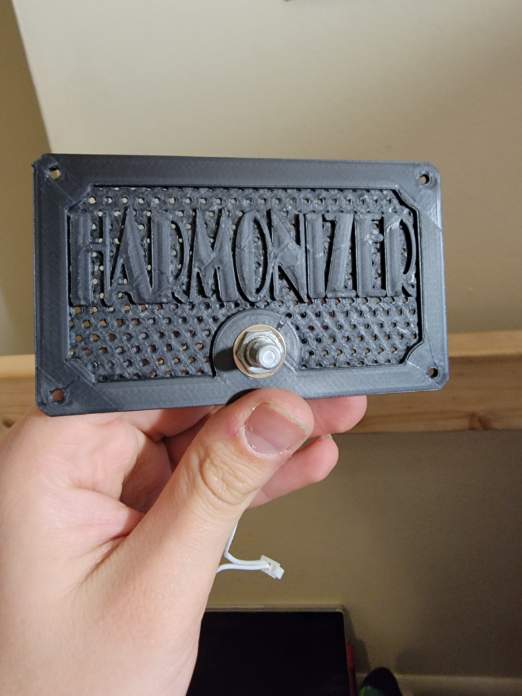
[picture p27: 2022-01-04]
design/assembly_images/Harmonizer_faceplate.png

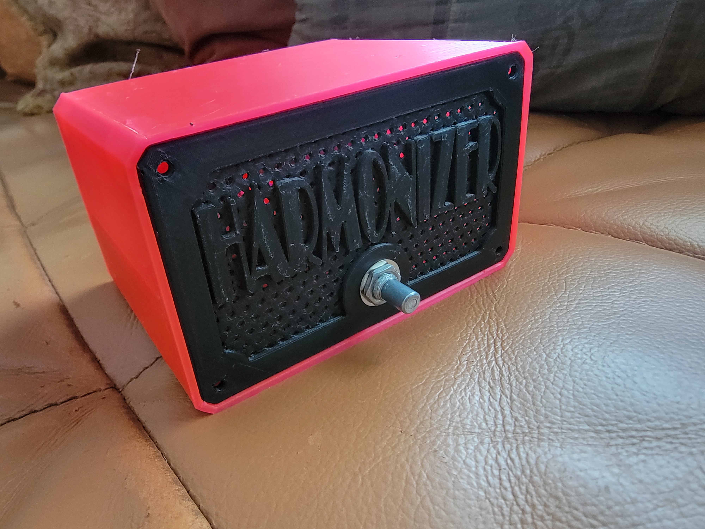
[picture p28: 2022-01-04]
design/assembly_images/Harmonizer_front.png

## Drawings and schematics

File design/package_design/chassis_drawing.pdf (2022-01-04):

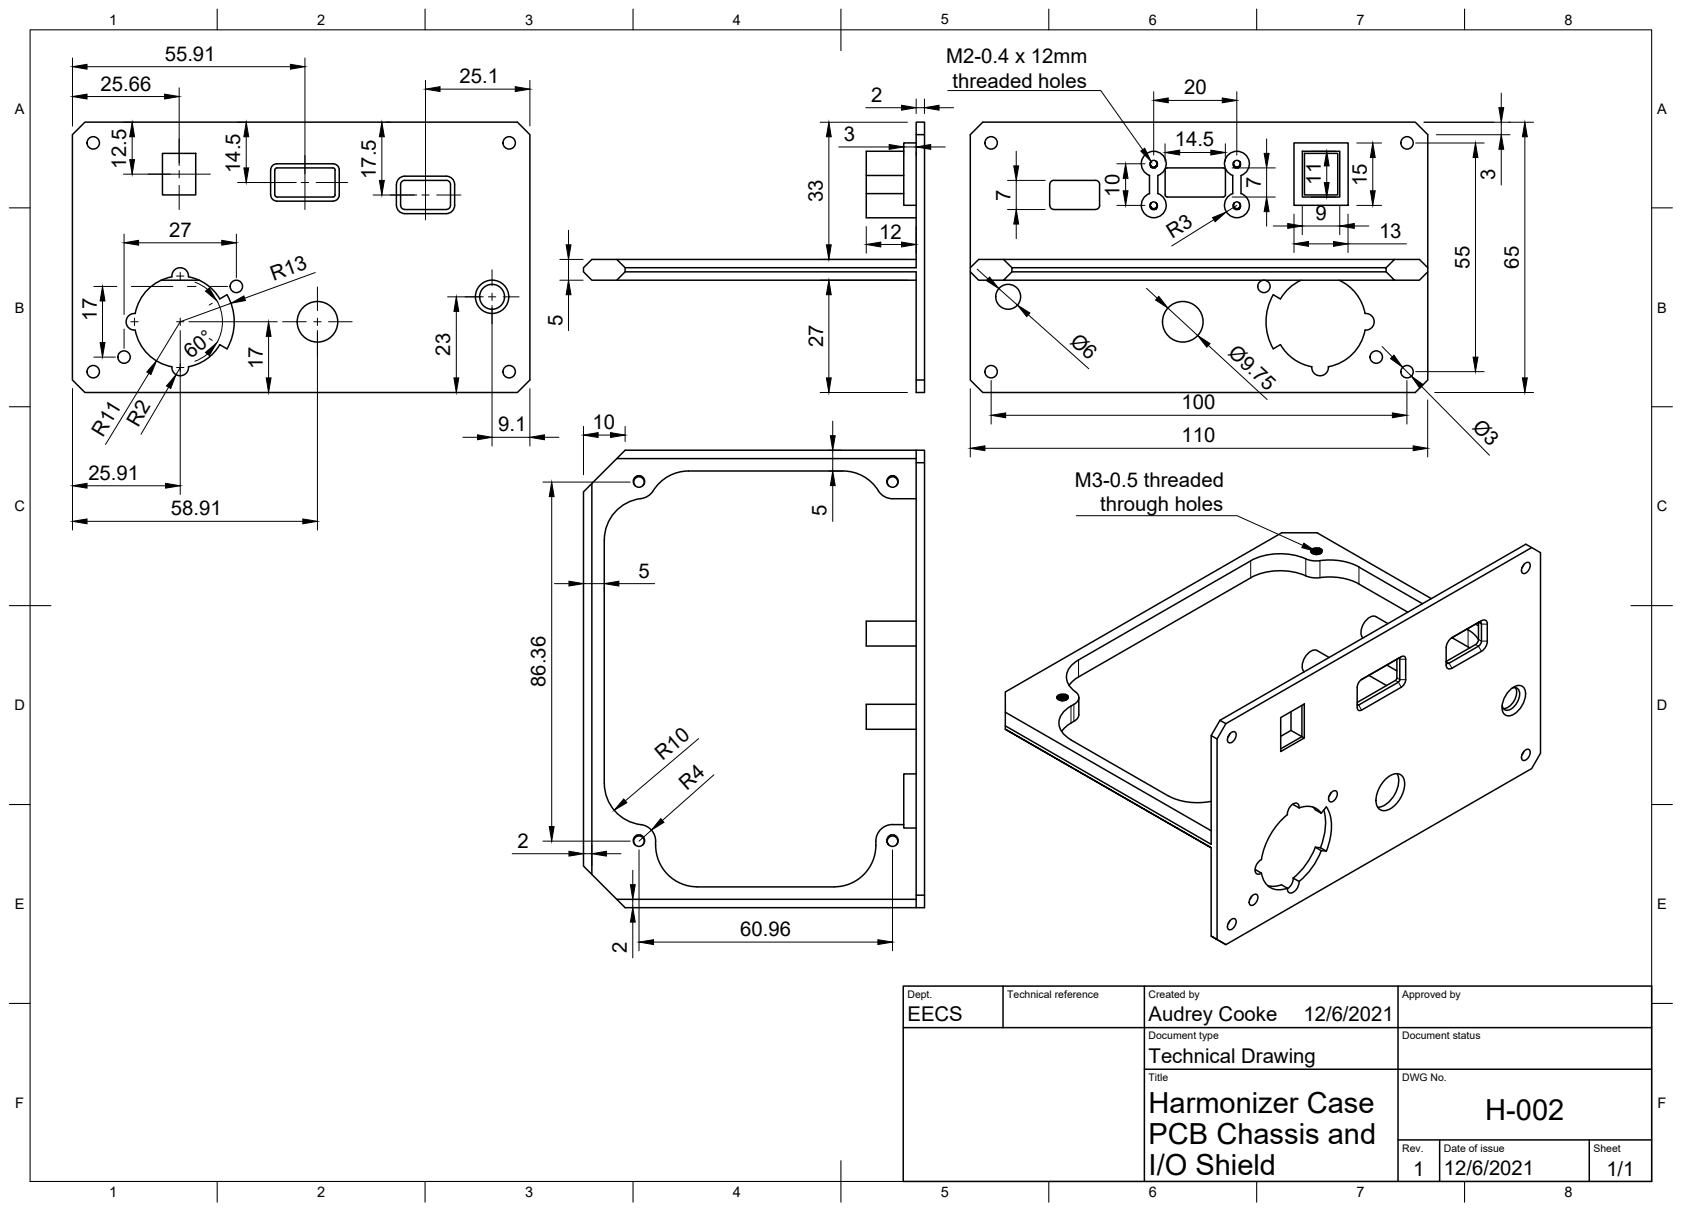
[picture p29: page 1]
Title; DWG No.; Rev.; Date of issue; Sheet; I/O Shield; Harmonizer Case; M3-0.5 threaded through holes; M2-0.4 x 12mm threaded holes

Dept. EECS | Technical reference | Created by Audrey Cooke 12/6/2021 | Approved by

Document type Technical Drawing | Document status

PCB Chassis and

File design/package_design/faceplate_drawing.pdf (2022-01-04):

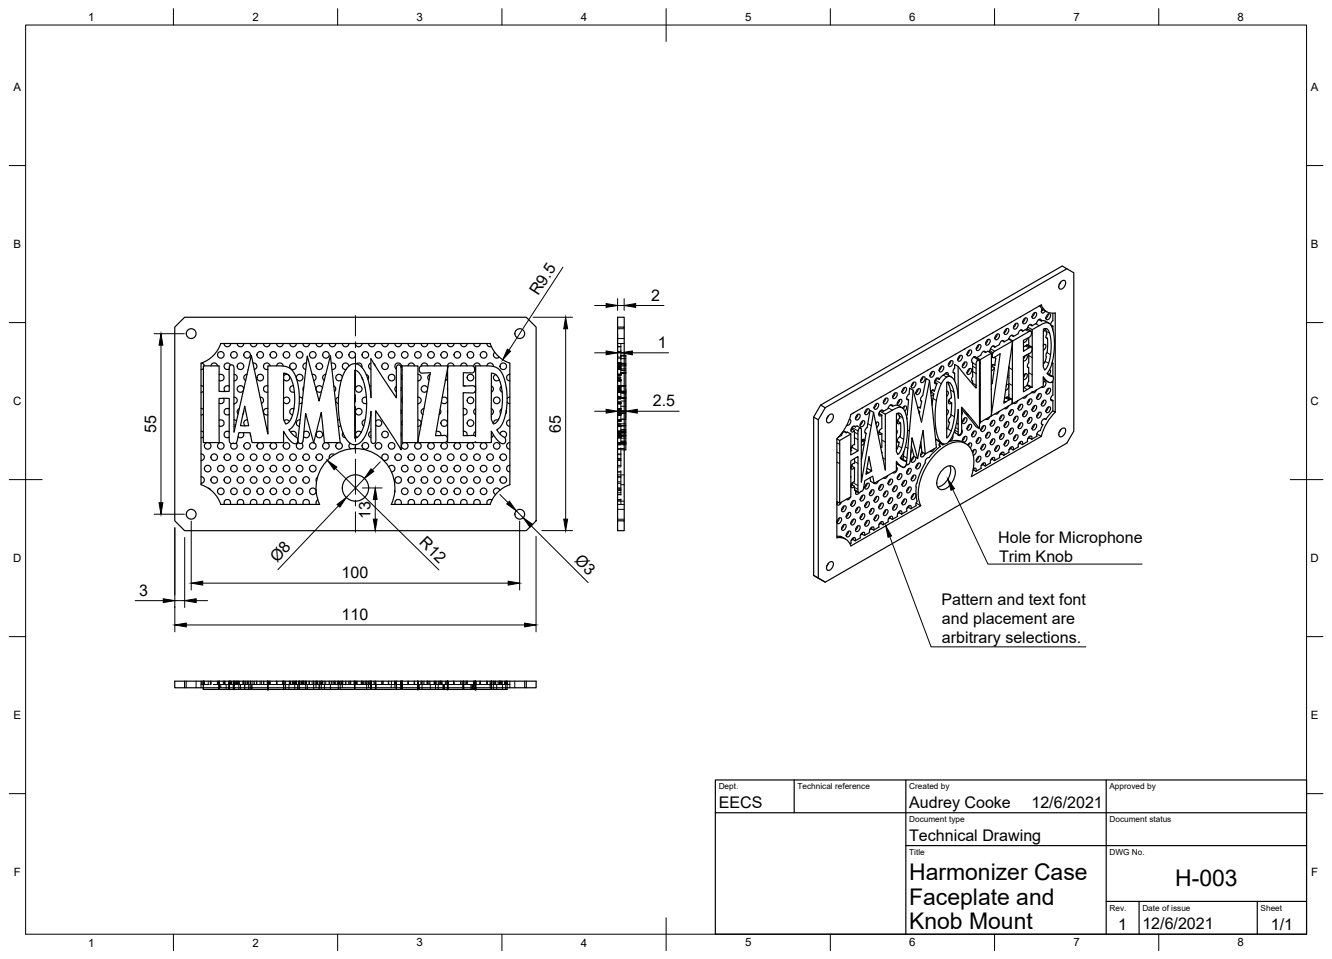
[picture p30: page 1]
Title; DWG No.; Rev.; Date of issue; Sheet; Knob Mount; Faceplate and; Harmonizer Case; EECS; Audrey Cooke 55; Ø3 Trim Knob

Hole for Microphone

Pattern and text font
and placement are
arbitrary selections.

Dept. | Technical reference | Created by 12/6/2021 | Approved by

Document type Technical Drawing | Document status

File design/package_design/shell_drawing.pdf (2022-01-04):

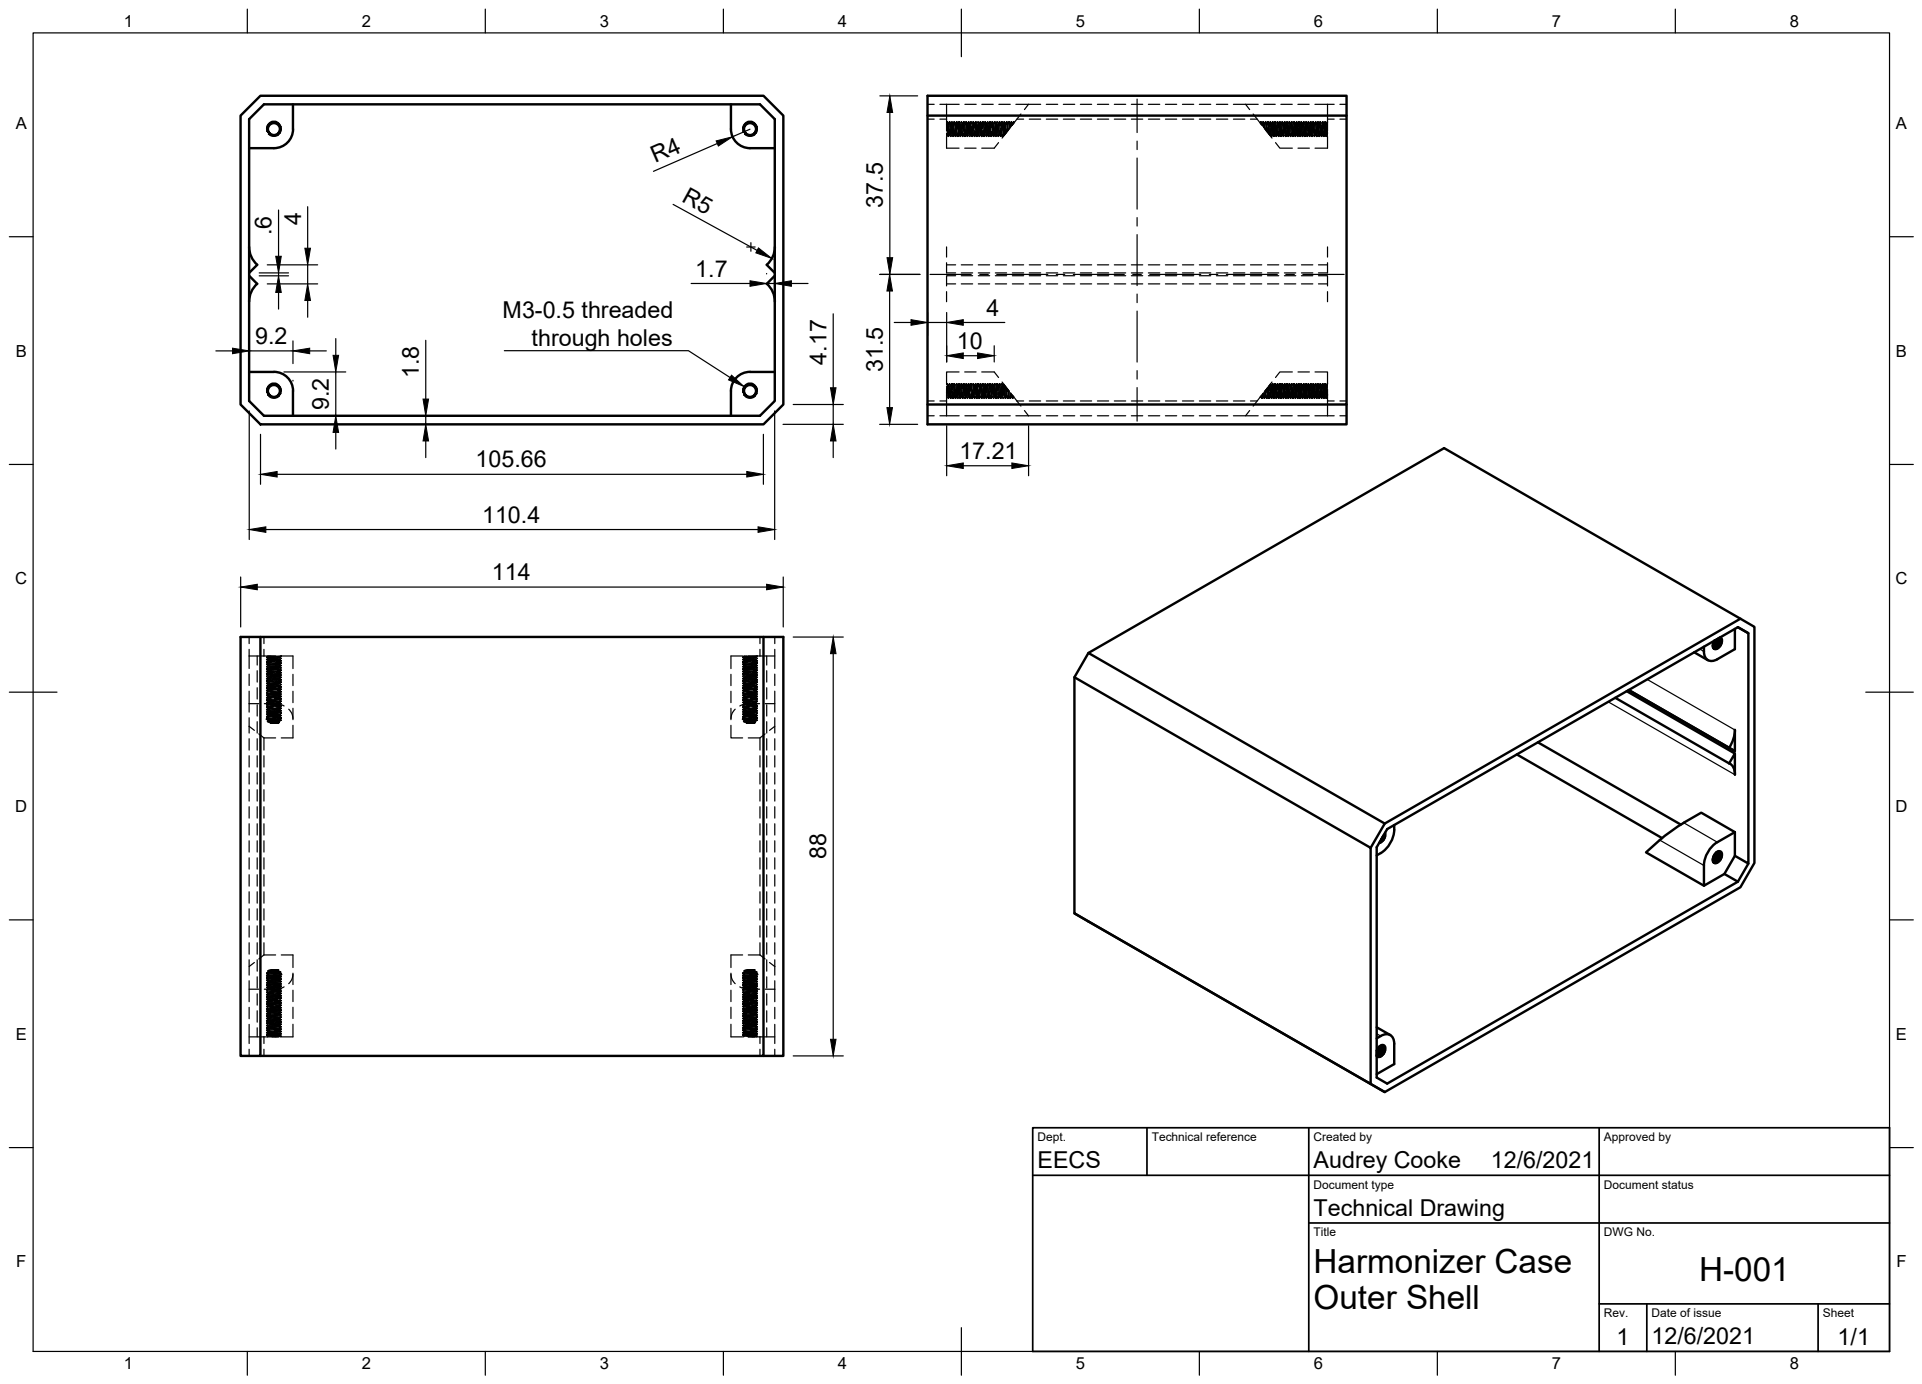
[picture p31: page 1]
Title; DWG No.; Rev.; Date of issue; Sheet; Outer Shell; Harmonizer Case; M3-0.5 threaded; through holes

Dept. EECS | Technical reference | Created by Audrey Cooke 12/6/2021 | Approved by

Document type Technical Drawing | Document status

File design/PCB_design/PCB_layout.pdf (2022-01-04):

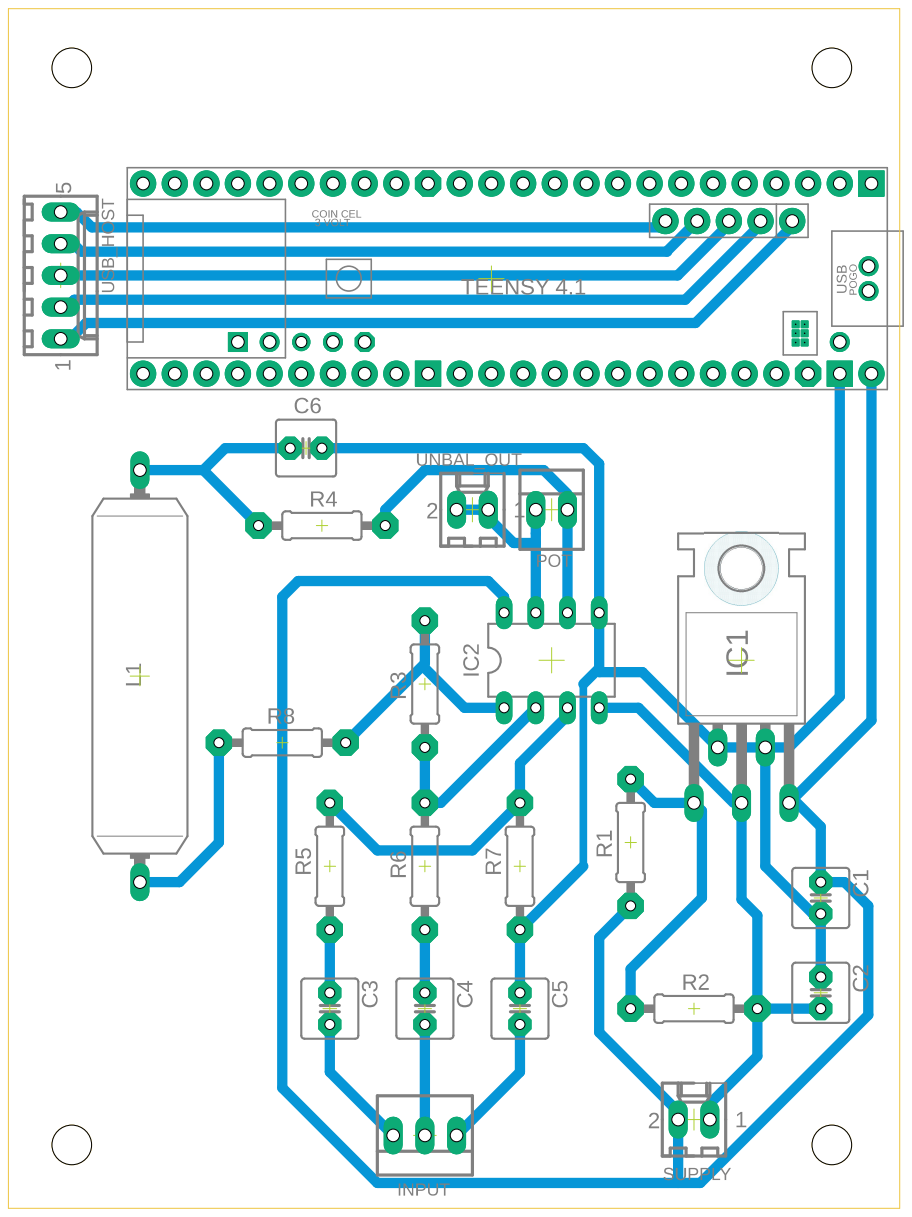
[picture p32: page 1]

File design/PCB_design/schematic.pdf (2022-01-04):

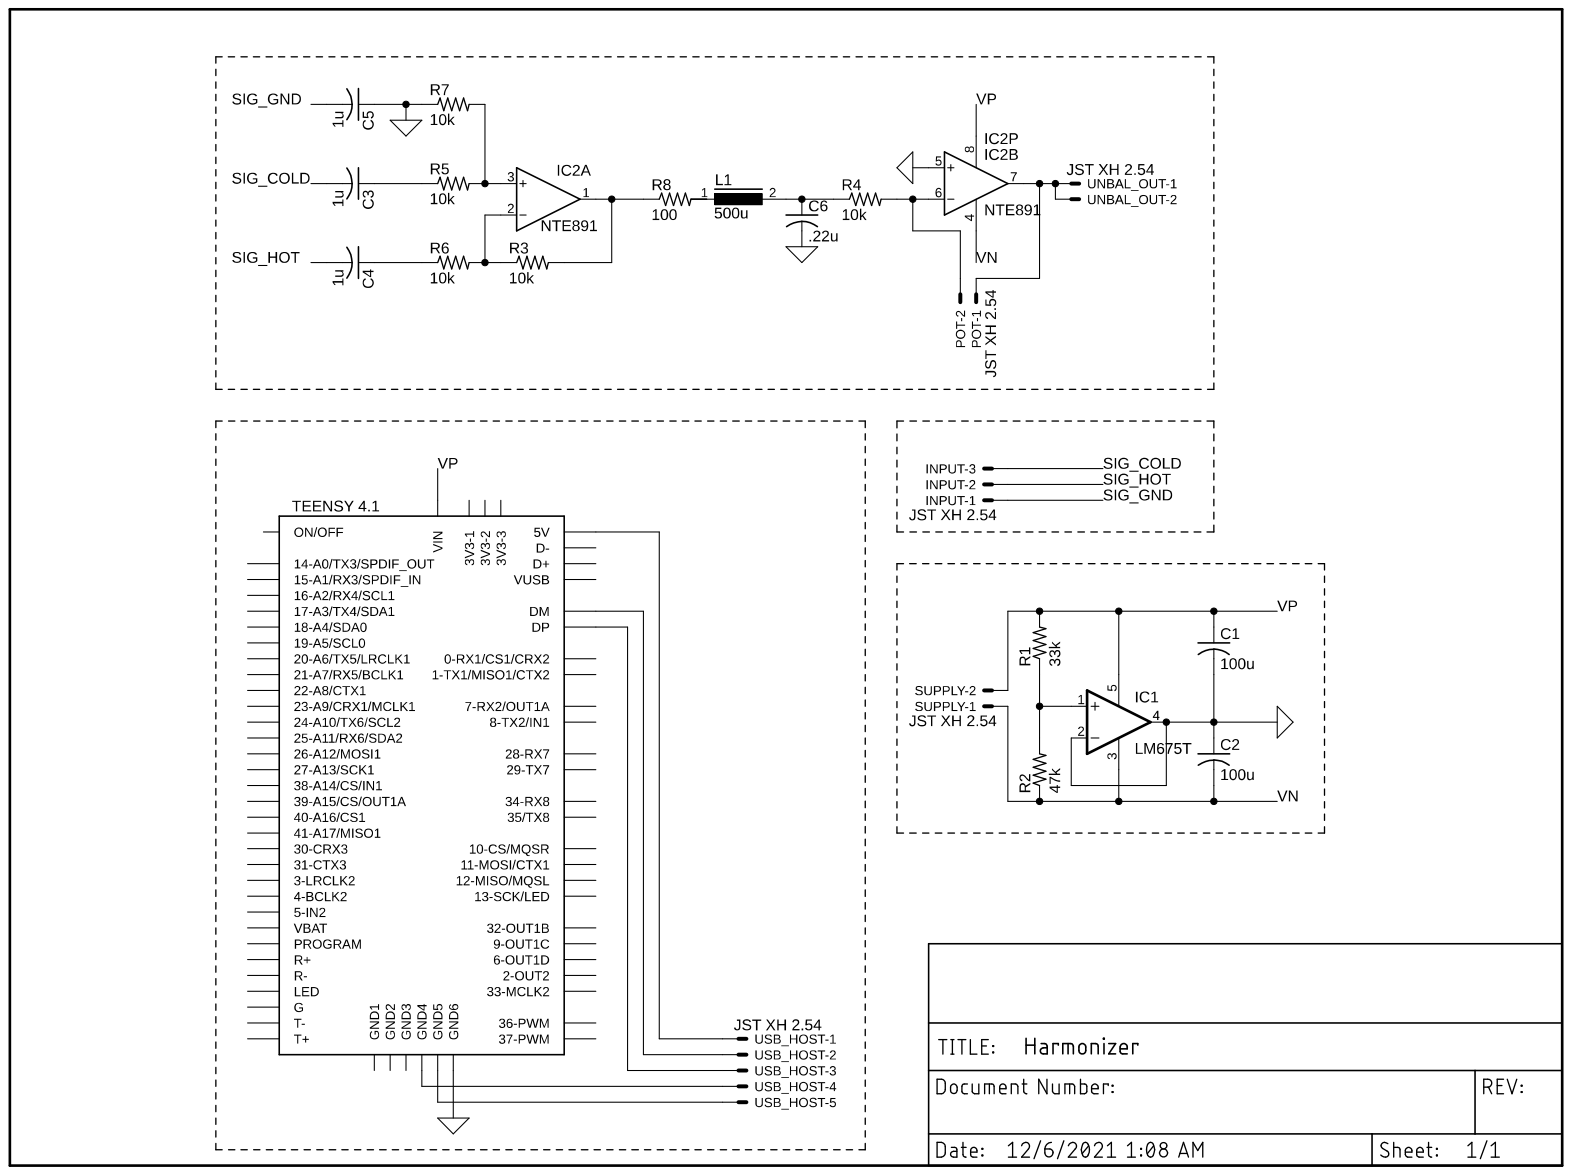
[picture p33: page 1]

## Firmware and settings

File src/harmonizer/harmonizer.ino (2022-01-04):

/*
	This is the driver Teensy sketch for our harmonizer. In this file, 
	four pitch shifting objects are created and mixed together with
	an unprocessed version of the input signal. This sketch also handles
	MIDI messages from an external host, as well as handling messages 
	where the teensy is acting as it's own host. The MIDI notes are then
	delegated to the pitch shifting objects by means of a queue structure.
*/
#include <USBHost_t36.h>
#include <Audio.h>
#include <Wire.h>
#include <SD.h>
#include <SPI.h>
#include <SerialFlash.h>


#define NOTE_LIMIT 4
  
const int myInput = AUDIO_INPUT_LINEIN;

struct MidiNote {
	byte channel, note, velocity;
};

bool operator==(const MidiNote& LHS, const MidiNote RHS) {
	return LHS.channel == RHS.channel && LHS.note == RHS.note;
}

//queue structure that handles note delegation between the pitch shifting objects
class NoteQueue {
private:
	static const size_t max_elts = NOTE_LIMIT;
	size_t num_elts = 0;
	size_t start_location = 0;

	MidiNote note_array[max_elts];

public:
	NoteQueue() {
		for (size_t i = 0; i < max_elts; ++i) note_array[i] = { 0,0,0 };
	}

	//Pop the first item from the note queue
	void pop_front() {
		if (!empty()) {
			at_helper(0) = { 0,0,0 };
			start_location = (start_location + 1) % max_elts;
			--num_elts;
		}
	}

	void push_back(const MidiNote& note) {
		if (!contains(note)) {
			if (num_elts == max_elts) pop_front();
			at_helper(num_elts) = note;
			++num_elts;
		}
	}

	const MidiNote& at(const size_t index) {
		return at_helper(index);
	}

	bool remove(const MidiNote& note) {
		//Find the element. If it isn't in the queue, return false.
		bool found = false;
		size_t found_index = 0;

		//Go through and find. If found, shift everything left 1
		for (size_t i = 0; i < size(); ++i) {
			if (at_helper(i) == note) {
				found = true;
				num_elts--;
			}
			if (found) at_helper(i) = at_helper(i + 1);
		}

		//Zero out the last element just because
		if (found) at_helper(size()) = { 0,0,0 };

		return found;
	}

	MidiNote& operator[](const size_t index) {
		return at_helper(index);
	}

	size_t size() const {
		return num_elts;
	}

	bool empty() {
		return num_elts == 0;
	}

	bool contains(const MidiNote& note) {
		for (size_t i = 0; i < size(); ++i) {
			if (at(i) == note)  return true;
		}
		return false;
	}

	void clear() {
		while (!empty()) pop_front();
	}

private:
	MidiNote& at_helper(const size_t index) {
		return note_array[(start_location + index) % max_elts];
	}

};

USBHost myusb;
USBHub hub1(myusb);
MIDIDevice midi1(myusb);
NoteQueue MIDINotes;

AudioInputI2S         audioInput;         // audio shield: mic or line-in
AudioOutputI2S        audioOutput;        // audio shield: headphones & line-out
AudioAnalyzeNoteFrequency analysis;

AudioPitchShift pitch1;
AudioPitchShift pitch2;
AudioPitchShift pitch3;
AudioPitchShift pitch4;

AudioMixer4 pitchmixer;
AudioMixer4 mastermixer;

//send input to a pitch estimation object
AudioConnection c1(audioInput, 0, analysis, 0);

//send input to four different pitch shifting objects
AudioConnection c3(audioInput, 0, pitch1, 0);
AudioConnection d3(audioInput, 0, pitch2, 0);
AudioConnection d4(audioInput, 0, pitch3, 0);
AudioConnection d5(audioInput, 0, pitch4, 0);

//route the pitch shifters to a mixer
AudioConnection c4(pitch1, 0, pitchmixer, 0);
AudioConnection c5(pitch2, 0, pitchmixer, 1);
AudioConnection c6(pitch3, 0, pitchmixer, 2);
AudioConnection c7(pitch4, 0, pitchmixer, 3);

//route the pitch mixer and original input into a second mixer
AudioConnection c8(audioInput, 0, mastermixer, 0);
AudioConnection c9(pitchmixer, 0, mastermixer, 1);

//send the master mixer to the output
AudioConnection c10(mastermixer, 0, audioOutput, 0);
AudioConnection c11(mastermixer, 0, audioOutput, 1);

AudioControlSGTL5000 audioShield;

void setup() {
  Serial.begin(115200);
  delay(300);
  pinMode(LED_BUILTIN, OUTPUT);

  // allocate memory for the audio library
  AudioMemory(128);
  audioShield.enable();
  audioShield.volume(0.8 );
  
  //initialize mixer gains
  pitchmixer.gain(0,.75);
  pitchmixer.gain(1,.75);
  pitchmixer.gain(2,.75);
  pitchmixer.gain(3,.75);

  mastermixer.gain(0,.5);
  mastermixer.gain(1, 1);
  mastermixer.gain(2, 0);
  mastermixer.gain(3, 0);

  myusb.begin();
  usbMIDI.begin();

  //Host Mode MIDI handlers
  midi1.setHandleNoteOff(OnNoteOff);
  midi1.setHandleNoteOn(OnNoteOn);
  midi1.setHandleControlChange(OnControlChange);

  //Device Mode MIDI handlers
  usbMIDI.setHandleNoteOff(OnNoteOff);
  usbMIDI.setHandleNoteOn(OnNoteOn);
  usbMIDI.setHandleControlChange(OnControlChange);

  // Initialize the processing objects
  analysis.begin(.15);
  pitch1.begin();
  pitch2.begin();
  pitch3.begin();
  pitch4.begin();
  pitch1.set_new_period(0);
  pitch2.set_new_period(0);
  pitch3.set_new_period(0);
  pitch4.set_new_period(0);
  pitch1.set_period(300);
  pitch2.set_period(300);
  pitch3.set_period(300);
  pitch4.set_period(300);
}

enum class MIDItype { NONE, HOST_MODE, DEVICE_MODE };
MIDItype miditype = MIDItype::NONE;

void loop()
{	
	//set input pitch estimations when they are available
	if(analysis.available()){
		float freq = analysis.read();
    Serial.println(freq);
		float period = 44100/freq;
		pitch1.set_period(period);
		pitch2.set_period(period);
		pitch3.set_period(period);
		pitch4.set_period(period);
	}

	//Host Mode: if MIDI keyboard is plugged in, use midi1
	if (midi1) {
		//Did we switch to this mode? If so clear the queue, turn on the LED for confirmation
		if (miditype != MIDItype::HOST_MODE) {
			miditype = MIDItype::HOST_MODE;
			MIDINotes.clear();
			digitalWrite(LED_BUILTIN, HIGH);
			Serial.println("Booting into Host Mode");
		}

		myusb.Task();
		midi1.read();
	}

	//Device Mode: if no MIDI keyboard plugged in, use usbMIDI
	else {
		//Did we switch to this mode? If so clear the queue, turn off the LED for confirmation
		if (miditype != MIDItype::DEVICE_MODE) {
			miditype = MIDItype::DEVICE_MODE;
			MIDINotes.clear();
			digitalWrite(LED_BUILTIN, LOW);
			Serial.println("Booting into Device Mode");
		}

		usbMIDI.read();
	}

}

void OnNoteOn(byte channel, byte note, byte velocity)
{
	MidiNote midi_note = { channel, note, velocity };
	MIDINotes.push_back(midi_note);
	updateTargets();
}

void OnNoteOff(byte channel, byte note, byte velocity)
{
	MidiNote midi_note = { channel, note, velocity };
	MIDINotes.remove(midi_note);
	updateTargets();
}

void OnControlChange(byte channel, byte control, byte value)
{
	//TODO: How can we use control changes to mess with params?
	Serial.print("Control Change, ch=");
	Serial.print(channel);
	Serial.print(", control=");
	Serial.print(control);
	Serial.print(", value=");
	Serial.print(value);
	Serial.println();
}

void updateTargets() {
	//set pitch targets based on MIDI queue
	pitch1.set_new_period(noteToPeriod(MIDINotes[0].note));
	pitch2.set_new_period(noteToPeriod(MIDINotes[1].note));
	pitch3.set_new_period(noteToPeriod(MIDINotes[2].note));
	pitch4.set_new_period(noteToPeriod(MIDINotes[3].note));

	Serial.println();
}


float noteToPeriod(int note) {
	if (note == 0) return 0.0;

	float a = 440; //frequency of A
	float f =  (a / 32) * pow(2, ((note - 9) / 12.0));

	return 44100. / f;
}

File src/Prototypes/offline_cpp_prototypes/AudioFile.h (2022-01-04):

   
//=======================================================================
/** @file AudioFile.h
 *  @author Adam Stark
 *  @copyright Copyright (C) 2017  Adam Stark
 *
 * This file is part of the 'AudioFile' library
 *
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
 * You should have received a copy of the GNU General Public License
 * along with this program.  If not, see <http://www.gnu.org/licenses/>.
 */
//=======================================================================

#ifndef _AS_AudioFile_h
#define _AS_AudioFile_h

#include <iostream>
#include <vector>
#include <cassert>
#include <string>
#include <cstring>
#include <fstream>
#include <unordered_map>
#include <iterator>
#include <algorithm>

// disable some warnings on Windows
#if defined (_MSC_VER)
    __pragma(warning (push))
    __pragma(warning (disable : 4244))
    __pragma(warning (disable : 4457))
    __pragma(warning (disable : 4458))
    __pragma(warning (disable : 4389))
    __pragma(warning (disable : 4996))
#elif defined (__GNUC__)
    _Pragma("GCC diagnostic push")
    _Pragma("GCC diagnostic ignored \"-Wconversion\"")
    _Pragma("GCC diagnostic ignored \"-Wsign-compare\"")
    _Pragma("GCC diagnostic ignored \"-Wshadow\"")
#endif

//=============================================================
/** The different types of audio file, plus some other types to 
 * indicate a failure to load a file, or that one hasn't been
 * loaded yet
 */
enum class AudioFileFormat
{
    Error,
    NotLoaded,
    Wave,
    Aiff
};

//=============================================================
template <class T>
class AudioFile
{
public:
    
    //=============================================================
    typedef std::vector<std::vector<T> > AudioBuffer;
    
    //=============================================================
    /** Constructor */
    AudioFile();
    
    /** Constructor, using a given file path to load a file */
    AudioFile (std::string filePath);
        
    //=============================================================
    /** Loads an audio file from a given file path.
     * @Returns true if the file was successfully loaded
     */
    bool load (std::string filePath);
    
    /** Saves an audio file to a given file path.
     * @Returns true if the file was successfully saved
     */
    bool save (std::string filePath, AudioFileFormat format = AudioFileFormat::Wave);
        
    //=============================================================
    /** @Returns the sample rate */
    uint32_t getSampleRate() const;
    
    /** @Returns the number of audio channels in the buffer */
    int getNumChannels() const;

    /** @Returns true if the audio file is mono */
    bool isMono() const;
    
    /** @Returns true if the audio file is stereo */
    bool isStereo() const;
    
    /** @Returns the bit depth of each sample */
    int getBitDepth() const;
    
    /** @Returns the number of samples per channel */
    int getNumSamplesPerChannel() const;
    
    /** @Returns the length in seconds of the audio file based on the number of samples and sample rate */
    double getLengthInSeconds() const;
    
    /** Prints a summary of the audio file to the console */
    void printSummary() const;
    
    //=============================================================
    
    /** Set the audio buffer for this AudioFile by copying samples from another buffer.
     * @Returns true if the buffer was copied successfully.
     */
    bool setAudioBuffer (AudioBuffer& newBuffer);
    
    /** Sets the audio buffer to a given number of channels and number of samples per channel. This will try to preserve
     * the existing audio, adding zeros to any new channels or new samples in a given channel.
     */
    void setAudioBufferSize (int numChannels, int numSamples);
    
    /** Sets the number of samples per channel in the audio buffer. This will try to preserve
     * the existing audio, adding zeros to new samples in a given channel if the number of samples is increased.
     */
    void setNumSamplesPerChannel (int numSamples);
    
    /** Sets the number of channels. New channels will have the correct number of samples and be initialised to zero */
    void setNumChannels (int numChannels);
    
    /** Sets the bit depth for the audio file. If you use the save() function, this bit depth rate will be used */
    void setBitDepth (int numBitsPerSample);
    
    /** Sets the sample rate for the audio file. If you use the save() function, this sample rate will be used */
    void setSampleRate (uint32_t newSampleRate);
    
    //=============================================================
    /** Sets whether the library should log error messages to the console. By default this is true */
    void shouldLogErrorsToConsole (bool logErrors);
    
    //=============================================================
    /** A vector of vectors holding the audio samples for the AudioFile. You can 
     * access the samples by channel and then by sample index, i.e:
     *
     *      samples[channel][sampleIndex]
     */
    AudioBuffer samples;
    
    //=============================================================
    /** An optional iXML chunk that can be added to the AudioFile. 
     */
    std::string iXMLChunk;
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

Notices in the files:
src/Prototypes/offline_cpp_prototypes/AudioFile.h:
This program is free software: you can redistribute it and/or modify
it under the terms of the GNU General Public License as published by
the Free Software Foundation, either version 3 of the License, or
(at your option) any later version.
